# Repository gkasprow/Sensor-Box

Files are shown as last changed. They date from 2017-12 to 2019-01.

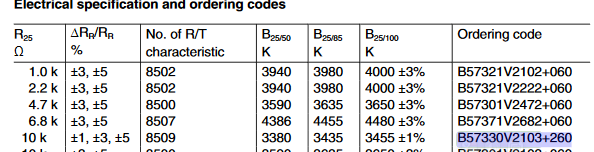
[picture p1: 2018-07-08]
Sensor_Box_Hardware/Sensor-Box/Sensor_Box_PWR_Backup/Thermistor.PNG

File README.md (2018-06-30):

# Sensor-Box
Multichannel standarized enviorement for home automation and other MQTT applications

This is design of modular, DIN-based system for hme automation and industrial control.
There are several great open-source SW enviorements like Cayenne, Blynk, Node Red. They are used to control breadboard stuff built with Arduino, RPI and extension modules.
What I miss the most is well designed hardware that fully explores potential of the software.
So I designed several base and extension modules. The idea is very simple - there is controller module based on Arduino, ESP32 or Linux platform.
From its left side one plugs connectivity modules like Ethernet, LoRa, GPRS and supply like DC, AC, PoE, battery backup.
From its right side one can plug any number of extensions like energy meters, relays, Lighting drivers. One can also connect external sensors using CAN bus.
Several existing technologies were used to build the system, to count a few: HAPCAN, Arduino, Node Red, Cayenne.
More information is available on Wiki page.

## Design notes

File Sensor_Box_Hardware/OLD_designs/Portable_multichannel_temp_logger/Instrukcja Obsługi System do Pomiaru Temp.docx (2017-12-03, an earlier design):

Wielokanałowy system do pomiaru temperatury

User Manual

1. Podstawowa obsługa urządzenia

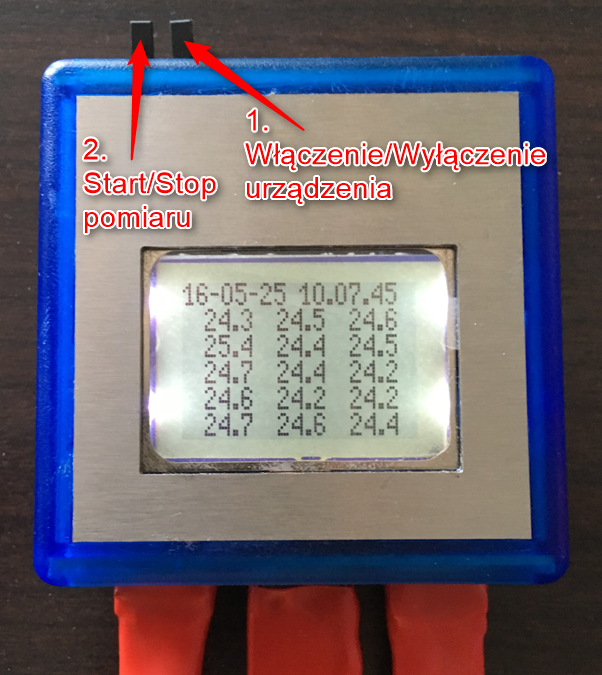
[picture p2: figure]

2. Zapis na kartę SD.

Urządzenie automatycznie zapisuje wszystkie pomiary raz z ich czasem oraz wszystkie wyświetlane komunikaty do pliku LOG.TXT.

3. Konfiguracja urządzenia

Konfiguracja urządzenia możliwa jest zmianę wartości parametrów pliku config.txt. Lista parametrów przedstawiona jest w poniższej tabeli:

Parametr: | Opis: | Przykład definicji:
D | Aktualna wartość data | D20160505 (D20YYMMDD)
T | Aktualny wartość czasu | T201238 (THHMMSS)
M | Tryb Kalibracyjny | M
m | Tryb Pomiarowy | m
N | Włączenie pomiaru poszczególnego czujnika, x- numer czujnika, defaultowo czujnik jest wyłaczony | N10 (Nx)
F | Wyłączenie pomiaru poszczególnego czujnika, x- numer czujnika | F10 (Fx)
c | Wartość wyjścia przetwornika w temperatu- rze T0, x – numer czujnika, yyyyyyy – wyjście przetwornika | c01 3018165 (cxx yyyyyyy)
C | Wartość wyjścia przetwornika w temperatu rze T1, x – numer czujnika, yyyyyyy – wyjście przetwornika | c01 4770612 (Cxx yyyyyyy)
T0 | Mniejsza temperatura do kalibracji czujnika, x – wartość temperatury | T0 0 (T0 x)
T1 | Większa temperatura do kalibracji czujnika, x – wartość temperatury | T1 100 (T1 x)
I | Czas opóźnienia pomiędzy kolejnymi pomiarami czujników, gdzie x – czas wyrażony w milisekundach | I500 (I x)

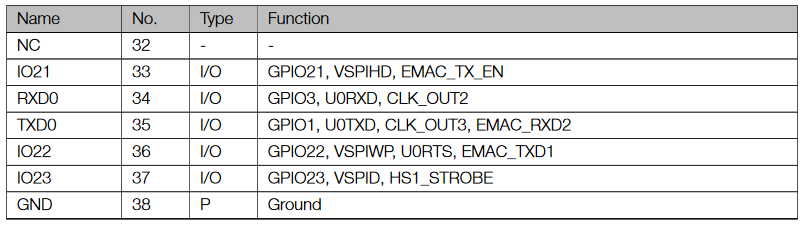
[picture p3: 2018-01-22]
Sensor_Box_Hardware/Sensor-Box/Sensor_Box_Hub/ESP32-2.PNG

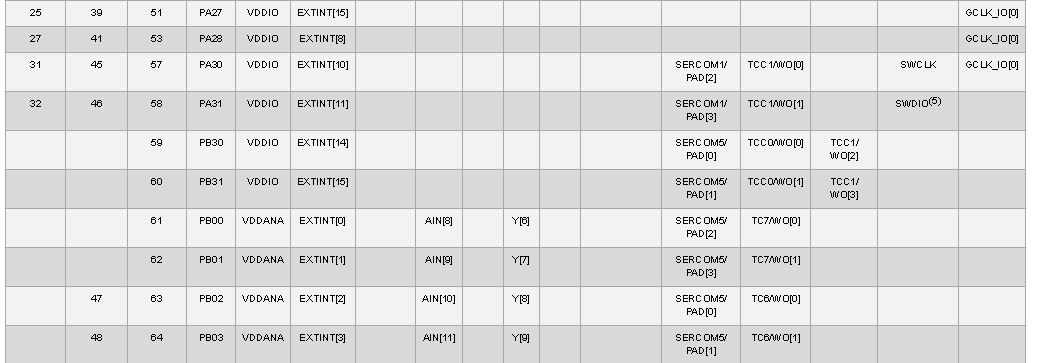
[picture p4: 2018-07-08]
Sensor_Box_Hardware/Sensor-Box/Sensor_Box_Hub_SAMD21/ATSAMD21c.PNG

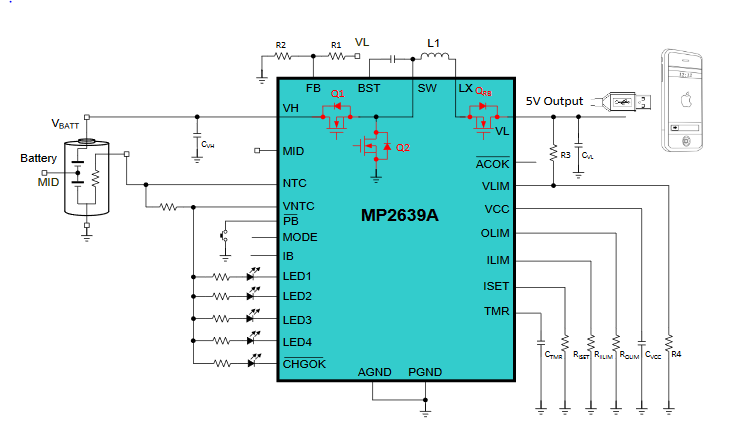
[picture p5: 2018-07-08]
Sensor_Box_Hardware/Sensor-Box/Sensor_Box_PWR_Backup/app_sch.PNG

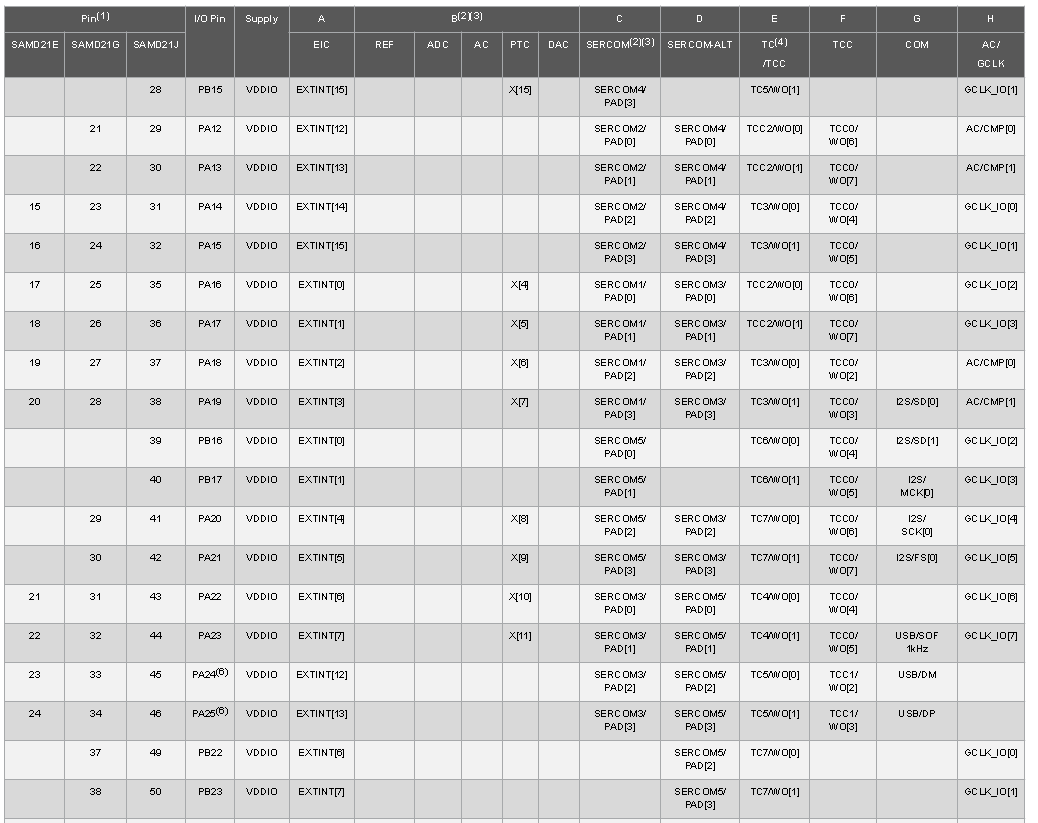
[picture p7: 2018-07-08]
Sensor_Box_Hardware/Sensor-Box/Sensor_Box_Hub_SAMD21/ATSAMD21b.PNG

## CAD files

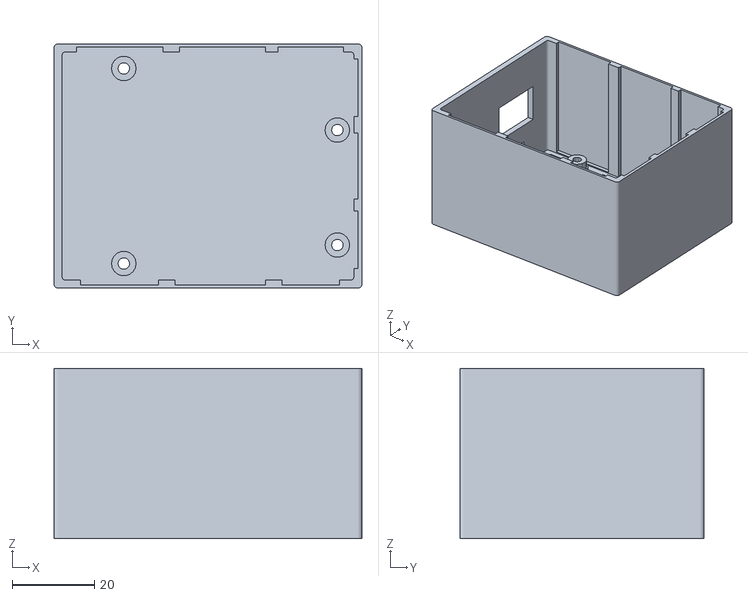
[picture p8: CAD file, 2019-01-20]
LoRa_router/Arduino_box.stl
75.0 x 59.5 x 41.5

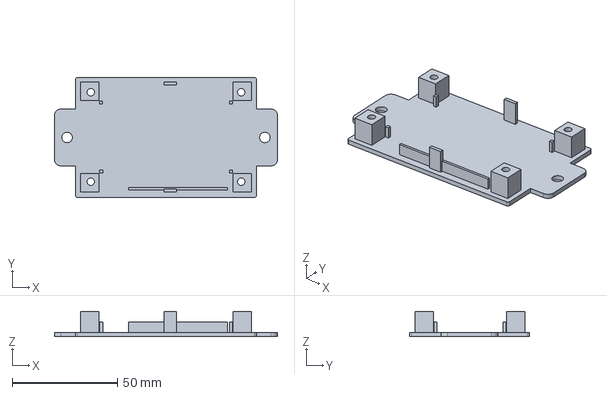
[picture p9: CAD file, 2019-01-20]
Sensor_Box_Hardware/Sensor-Box/Sensor_Box_CAN_SENS/Enclosure/Bottom.stp
106.0 x 57.0 x 12.0 mm

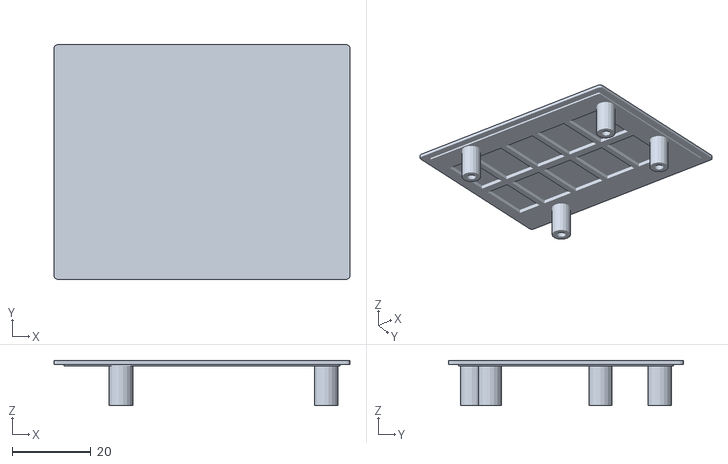
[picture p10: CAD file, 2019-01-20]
LoRa_router/lid.stl
75.0 x 59.5 x 11.5

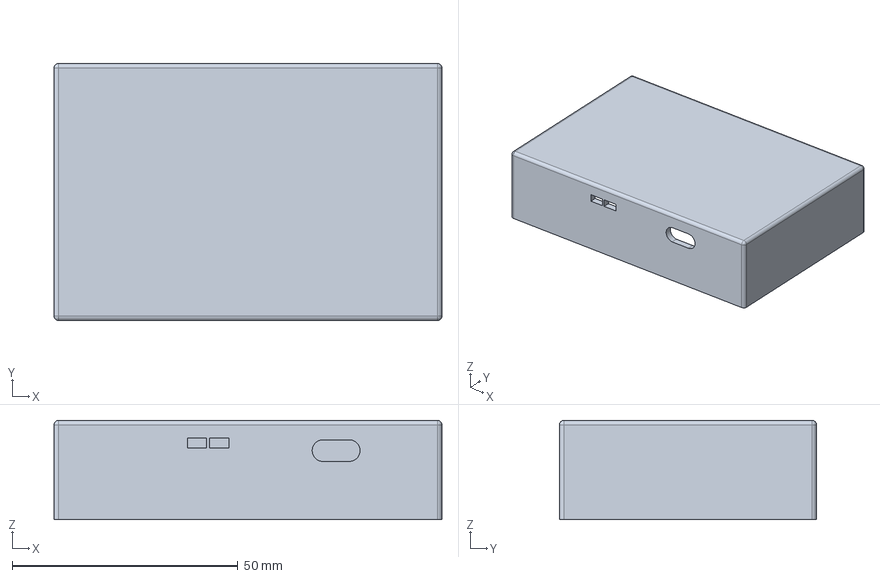
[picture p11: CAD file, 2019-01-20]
Sensor_Box_Hardware/Sensor-Box/Sensor_Box_CAN_SENS/Enclosure/Top.stp
86.0 x 57.0 x 22.0 mm

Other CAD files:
Sensor_Box_Hardware/Sensor-Box/Sensor_Box_CAN_SENS/Enclosure/Bottom.stl
Sensor_Box_Hardware/Sensor-Box/Sensor_Box_CAN_SENS/Enclosure/Top.stl

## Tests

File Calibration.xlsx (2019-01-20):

Voltage ratio | 0.001023751024 | Vout/Vin | Based on your input voltage divider ratios |  |  |  |  |  | L Line Input Impedance | 1000 | Ohm
Current ratio | 0.0145631068 | Vout/Ain | Based on your input current shunt/CT ratios |  |  |  |  |  | V Channel Input Impedance | 975800 | kOhm
 |  |  |  |  |  |  |  |  |  |  |  |  | Impulse converter
MMode |  |  |  |  |  |  |  |  |  |  |  |  | 973 | W
Lgain= | 100: Gain 1 |  |  |  | 100 |  |  |  |  | 1000000000 |  |  | 3.699897225 | seconds per impulse | 0.2702777778 | Hz
Ngain= | 10: Gain 1 |  |  |  | 10 |  |  |  |  |  |  |  | 973 | impulses in one hour | 0.2197802198 | Hz
LNSel= | 1: Meter on L line |  |  |  | 1
DisHPF= | 00: HPF1 and HPF0 |  |  |  | 00
Amod= | 0: Fwd or rev energy pulse output |  |  |  | 0
Rmod= | 0: Fwd or rev reactive energy pulse output |  |  |  | 0
Zxcon= | 10: All zero crossing |  |  |  | 10
Pthresh= | 0010: 3.125% |  |  |  | 0010
Mmode Reg= | 1001010000100010 |  |  |  |  |  |  |  |  |  |  | 0.1125728155
= | 10010100 | 00100010
= | 94 | 22
Mmode Reg= | 0x9422
PL Constant
UN= | 300 | V | Reference voltage, unit is V
Ib= | 30 | A | Basic current, unit is A
GL= | 1 | V/V | L line current circuit gain
VL= | 307.13 | mV | Sampling voltage of the L line circuit at Ib, unit is mV
VU= | 1000.0 | mV | Sampling voltage of the voltage circuit at UN, unit is mV
MC= | 1000 | imp/kWh | Pulse constant of the energy meter, unit is imp/kWh
PL_Constant= | 28626153
= | 01B4CCE9
PLconstH(0x21)= | 0x01B4
PLconstL(0x22)= | 0xCCE9
Small-Power Mode and Power Offset Compensation
1. Disconnect the current circuit of the energy meter;
2. Write '0xA987' to the SmallPMod register (04H) to enter small-power mode
3. Read out L / N line active / reactive power in small-power mode many times to get a mean value;
4. Write the complement of the above mean value to the corresponding L / N line active / reactive power offset registers;
5. Write any non-0xA987 value to the SmallPMod register (04H) to exit small-power mode
L Line Gain Calibration (Calibrate PL Constant Energy Metering)
L line gain calibration is performed when power factor PF=1.0 and the current is Ib
ETSA Frequency | 0.269 | Hz | Pulse output frequency as measured from ETSA metering using photodiode.
My Frequency | 0.219 | Hz | Pulse output frequency as measured from my energymeter using photodiode.
Error % = | -18.58736059 | %
Lratio = | 0.2283105023 |  |  | 65536 |  | 1010 | 10 | 5
Lgain= | 7481 |  | 58054 |  |  | 0101
Lgain= | 0x1D39
Voltage RMS Gain and L Line Current RMS Gain
Vol_mea= | 422.3 | V | Readout value of the Urms register (49H) |  |  |  |  |  |  | 0.007766865298
Un= | 238 | V | Actual Voltage |  |  | hex |  |  |  | 0.2436527437 | 31.37079559
Ugainold= | 54372 |  | 26400 is the default value |  |  | D464
= | 30642
Ugain= | 0x77B2
Cur_meaL= | 1.02 | A | Readout value of the Urms register (49H)
Ib= | 1.02 | A | Actual Voltage
Igainold= | 31251 |  | 31251 is the default value |  |  | 7a13
= | 31251
Igain= | 0x7A13 |  |  | offset=0.003A |  | IgainL | 366
 |  |  |  |  |  |  | 16E
The current offset calibration should be performed at reference voltage and no current.
Calibration is performed by reading the current, multiplying it with the above Igain/2^16 and 2^8,
calculating the complement and writing the result to the L line current offset register (IoffsetL, 35H).
Calibration of voltage offset is similar to that of current offset, but voltage offset
calibration is not applicable for self-powered meter
Voltage Sag Setpoint
Un= | 230 | Nominal voltage
Ugain= | 30642 | From Voltage RMS Gain calc
x%= | 0.94 | 6% below nominal
SagTh = | 8174
SagTh = | 0x1FEE

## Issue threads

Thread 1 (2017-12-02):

CPU selection

gkasprow, 2017-12-02:
I was looking for several CPU options that Cayenne supports and that has all features I need.
And it seems that ESP32 is quite good choice due to its low price and plenty of features.
It lacks IOs, but this can be mitigated easily using low cost extenders.
I built simple test platform to see how already [available Ethernet code](https://github.com/espressif/esp-idf/tree/master/examples/ethernet/ethernet) works.
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
And after some tweaking it really works.  The oscillator needed capacitor circuit to fix an issue reported [here](https://hackaday.com/2017/04/18/enabling-ethernet-on-the-esp32/).

gkasprow, 2017-12-03:
Udate - I made running original ESP8266 code on it. Just a few changes in header file names - rename Wifi.h to ESP32_Wifi.h and comment  lines 43..46 in the file CayenneMQTTWiFiClient.h.
//            if (WiFi.status() == WL_NO_SHIELD) {
//                            CAYENNE_LOG("WiFi shield not present");
//                            while (true);
//            }

gkasprow, 2018-01-06:
Update - Cayenne now supports ESP32 as well, but only Wifi connectivity

gkasprow, 2018-01-06:
In many cases Ethernet connectivity will be needed. ESP32 is fine, but has limited IO resources, i.e. number of UARTS. I checked the  SAM9D21 CPU, popular in Arduino community, priced about 2.5$/pc CPU.
It works with CayenneMQTT library very well.
Cayenne offers several approaches - Arduino and RPi libraries which are configured using top - bottom approach where certain IO or channel is activated from web interface.
There is another library called CayenneMQTT which offer bottom-top approach where data channel is defined by MQTT message type, in the source code. And this is what we need.
So I connected SAM9D21 board from [RobotDyn](https://robotdyn.com/catalog/boards/samd21_m0/)
with Wiznet W5500 board, compiled Cayenne MQTT example design and it works.
So I will prepare 2 main boards - one with ESP8266 + optional Ethernet PHY board and another with SAMD21 with W5500 so developers have choice which way to go.

gkasprow, 2018-06-30:
I want to use Node Red as a main controller. It is very flexible solution and enables ability to integrate literally everything with everything. To make it possible, I designed board with Orange Pi module. But after first experiments I discovered that it takes really a lot of power (more than 5W) and gets very hot after a few minutes.
I found a [tiny board](https://onion.io/omega2/) that is very cheap (~10$), takes 0.6W, has WiFi and Ethernet and enough computing power to do he job.
So I redesigned the hub module to support both Orange Pi zero and Onion Omega 2+

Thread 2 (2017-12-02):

power meter IC selection

gkasprow, 2017-12-02:
I did some survey around power metering ICs.
There are low cost power meter modules from China: [PZEM-004](https://abra-electronics.com/sensors/sensors-current-en/pzem-004t-multifunction-power-monitoring.html) but their accuracy and safety is an issue. I decided to use very low cost chip from [Microchip](http://www.microchip.com/wwwproducts/en/ATM90E26) that has already support for [many platforms](https://github.com/whatnick/ATM90E26_Arduino).
There are also low cost [modules ](https://www.tindie.com/products/whatnick/atm90e26-breakout/) available. Low cost means that it is far less expensive than Microchip devkit.
So I connected things together and started playing with software.
I didn't wanted to use software UART. Anyway, for some strange reason it didn't wanted to work.
So I modified the code to work with hardware serial port on Arduino Leonardo.
Another thing I discovered with this code is that it needs plenty of iterations to calibrate to board. First you have to flash CPU, connect load, ampmpeter, voltmeter, power meter, read values, enter into the code, flash CPU again, then read checksum that the ATM90E26 produces, put it int other code and flash again. Definitely not the way to go.
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

I added Cayenne code and get some measurements via web application. So this approach seem to work well.
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

gkasprow, 2017-12-17:
I did first attempt to build single channel of energy meter in a way that it is scalable and can be extended to any number of channels.
So I assumed that it must be a multi-drop connectivity and the protocol.
There are a few of them : I2C, CAN, RS485, 3-state LVCMOS
For connectivity within same module simple I2C or LVCMOS would do the job.
Protocol could be I2C or MODBUS.
The idea is to daisy-chain several modules.
But we want to have identical modules, with no address switches or jumpers.
The best would be geographical addressing.
And the number of connector pins need to be minimised - preferably 4 or so.
So the idea is to use autoconfiguration during boot time. Something that resembles USB re-numeration.
This could work in following way:
- the master talks to the first device on the bus (address 0). Other devices are disconnected.
- the unit 1 responds (with address 0), master changes its address to 1
- then the unit1 connects (extends) the bus to the unit 2 using analogue switch.
- the mater talks to the second device on the bus (address 0). Units 3,4...n are disconnected
- then the unit 2 responds, master changes its address to 2
- the process continues until anything responds on address 0.
During re-numeration process, the master reads ID table of device that contains descriptor of what the unit does.
In this way after the process is done, we have a set of devices with unique addresses.

This approach works if each device is intelligent, it means that it contains some CPU.
There are very low cost, powerful Cortex M0 MCUs. Their price is below [1$](https://www.digikey.com/product-detail/en/microchip-technology/ATSAMD09D14A-MUT/ATSAMD09D14A-MUTTR-ND/5404071)
The MCU is powerful, i.e. has 4kB of SRAM, 16KB of FLASH and 2 serial interfaces that is sufficient for us.

I can imagine that such measurement channels could be placed side by side to form flat structure. This is critical in case of the fuse-boxes.
Below is the first estimate. Board size is 53.5 x 14mm
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
The board contains connectors for L, N and current transducer, energy metering IC, MCU, crystal, analogue switch and bus connectors.
One can imagine such board extending internal bus to external interface, i.e. MODBUS RTU

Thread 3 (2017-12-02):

Interface selection

gkasprow, 2017-12-02:
To make the stuff modular, we need to choose the interfaces.
We need a way to discover newly connected modules and to communicate with them.
The obvious choice is I2C, but it has one disadvantage - one node can block the bus.
We can of course add bus switches to mitigate such case.
Another thing is its speed. It is not that critical in case of sensor readout, but if you have several such modules, that can become a bottleneck. Good thins is that here are plenty of sensors with I2C interface. But they cannot be placed too far from the controller.

Another popular IFC is SPI.
It's high speed, only one slave is selected at a time.

UART is yet another interface. It's problematic in case of multi-channel controller because needs that much UART peripherals. Sending data is trivial, but reception is not because some sensors (air quality, thermometers, GPS) transmit data asynchronously. There are chips that one can hook up to the [SPI](https://www.nxp.com/docs/en/brochure/75015676.pdf) or[ I2C ](https://www.maximintegrated.com/en/products/interface/controllers-expanders/MAX3107.html)and have as many UART channels as needed. One need a MCU to hook up another type of sensor, however there are ICS that support [UART -I2C/SPI](https://www.nxp.com/docs/en/brochure/75015763.pdf) conversion

MODBUS RTU is much better in this sense because it responds only when requested. It's great and nice to have because one can use COTS components like energy meter, relays, motor controllers, etc. To hook up a sensor one need to use MCU.

Analog signal

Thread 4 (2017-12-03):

air quality sensor

gkasprow, 2017-12-03:
Recently I purchased a few [SDS011](https://www.google.pl/url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) sensors.
First one was connected to Arduino clone - Atmega wih Wiznet chip using a few lines of code.
I equipped it with PoE injection box and placed on my terrace. The house is heated using solid state pellet stove. I can easily observe moments when the stove switches on and switches off - the pollution level exceeds the normal value 10x. My neighbour has identical heating system so things gets worse twice. Luckily, since a few months a gas pipe was laid close to my property so luckily in a few weeks I will switch to much more "eco" heating system.
Example one week plot
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

Then I ported ESP8266 Cayenne wifi to ESP32.
I've noticed during a few weeks of operation that ESP8266 is not very stable. It managed to hang itself.
So I started with ESP32, connected SDS011 sensors and placed them side by side.
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

The measurements are far from what I'd expect
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

gkasprow, 2017-12-10:
Today I noticed quite strange dust level in Warsaw:
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
There are construction works nearby, and it seems that the developer is doing some dusty works right now. Fortunately I have particle filters installed at the air inlets, so inside of the flat don't see any changes.
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

gkasprow, 2017-12-10:
Today I built yet another version of the particle monitor. I used PMS7003 which analyses also PM1. There is ready to use Arduino library, only a few lines of code were needed to integrate it with Cayenne.
I want to use it to test various filter materials in the recuperation system inlet filter.
This is the code that averages 10 readout and publishes measurements every 10 seconds

```
void loop()
{
  if (pms.read(data))
  {
    Cayenne.loop();
if (AV_CNT++<10)
  {
  PM1_AV_Value += data.PM_AE_UG_1_0;
  PM2_5_AV_Value += data.PM_AE_UG_2_5;
  PM10_AV_Value += data.PM_AE_UG_10_0;
  }
else
  {
    AV_CNT=0;
      Cayenne.virtualWrite(0, lastMillis);
      Cayenne.virtualWrite(2,(float)(PM1_AV_Value/10));
      Cayenne.virtualWrite(3,(float)(PM2_5_AV_Value/10));
      Cayenne.virtualWrite(4,(float)(PM10_AV_Value/10));
      PM1_AV_Value = 0;
      PM2_5_AV_Value = 0;
      PM10_AV_Value = 0;
  }
  }

```

gkasprow, 2018-06-30:
I designed more or less final version of the sensor. It is accessible over CAN and supports PMS7003, HDC1000YPA and SGP30 sensors thus enabling complex air quality measurements.
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

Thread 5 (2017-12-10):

Modbus devices

gkasprow, 2017-12-10:
There are many popular industry-grade MODBUS devices that can be used for IoT purposes.
I purchased some of them: energy meters, humidity/temperature sensors, relay boards, UART-RS485 boards, DIN relays, etc.
So that's a pity that it is not supported by Cayenne environment.
So I did some quick setup to test how it works in practice.
I took ESP8266 devkit, ORNO energy meter, relay and built power switch with energy monitor. There are many such devices on Aliexpess, some of them are based on ESP8266. I tested one from Edimax and it works  but sometimes. While in local network it works just fine, outside of it works sometimes. So it is not the way to go. One idea is to replace the firmware with some alternative, another is to connect 15$ energy meter to 2$ ESP devkit and write a few lines of code. Modbus is already supported by Arduino so why not to try.
Here is the bricolage
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

the code is very simple:
``
    result = node.readHoldingRegisters(0, 9);
 if (result == node.ku8MBSuccess)
   {
    Cayenne.virtualWrite(4, (float)node.getResponseBuffer(0x00)/10,"voltage", "Volts"); //voltage
    Cayenne.virtualWrite(5, (float)node.getResponseBuffer(0x01)/10, "current", "Ampere");//current
    Cayenne.virtualWrite(6, (float)node.getResponseBuffer(0x02)/10, "freq", "Hertz" );//frequency
    Cayenne.virtualWrite(7, node.getResponseBuffer(0x03), "pow", "Watts");//Active power
    Cayenne.virtualWrite(8, node.getResponseBuffer(0x04), "pow", "Watts");//Reactive power
    Cayenne.virtualWrite(9, node.getResponseBuffer(0x05), "pow", "Watts");//Apparent power
    Cayenne.virtualWrite(10, (float)node.getResponseBuffer(0x06)/1000);//Power factor
    Cayenne.virtualWrite(11, (float)(node.getResponseBuffer(0x07) *256 + node.getResponseBuffer(0x08))/1000);// Active energy
    Cayenne.virtualWrite(12, node.getResponseBuffer(0x03), "pow", "Watts");//Active power
     }
	}
``

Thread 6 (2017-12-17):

Modularity and scalability

gkasprow, 2017-12-17:
As it was already [posted](https://github.com/gkasprow/Sensor-Box/issues/2#issuecomment-352221718), I plan to utilise modular construction which can be extended to visually any number of channels.
On the other hand, I want to have in addition:
- Ethernet
- PoE
- GSM module
- LiPo supply option
Enclosure is another issue that need to be discussed separately.
So far I sketched schematics for:
- power meter
- PoE
- Ethernet module
- Hub

The modules can be arranged in the following way:
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

On the left side we have PoE, then Ethernet, hub and 3 power meters.
At the moment the connectors are 4 pin, but I consider adding also I2C wires and one custom wire for remote firmware upgrade. Maybe +12V would be feasible for high power applications.

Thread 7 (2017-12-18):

Enclosure

gkasprow, 2017-12-18:
I'm looking for nice enclosure that fits both DIN rail and can work stand-alone.
It needs to be modular and low cost.
And it seems I found ideal candidate. They are produced by several manufacturers, i.e. [Camdenboss](http://camdenboss.com/interface-modules/mini-series-72mm-empty-modular-interface-supports) and OKW. Example from OKW:
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
They are available with DIN mounting and without it. The segments are below or just above 1 EUR.
Available widths: 11.25, 22.5, 45mm and multiples

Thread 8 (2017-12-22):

Connectors

gkasprow, 2017-12-22:
After long search I found connectors that fit the purpose very well.
They are low cost , below 1$ per piece, and are idiot-proof. Maximum pin count is 10 which is sufficient for our purpose.
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

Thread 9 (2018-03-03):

CAN support

gkasprow, 2018-03-03:
I build a house and started looking for a home automation system that has several features:
 - it is not wireless. I have so much issues with wireless system that I simply do not trust it. They are easy to jam, run on battery.
- I told electricians to install twisted pair cable along all switches and places where potentially will be equipment installed which I want to control. This includes gas furnace, recuperation, alarm, fire sensors, shutters etc.
- the home automation system need to be failure proof, I mean that once electronics is dead, all critical switches must work.
I started looking for a system that supports such operation mode over twisted pair and the only I found is KNX.
The drawback is that in every device one must use quite expensive transceiver. There are a few vendors, but the cheapest transceivers are 6$ at 100pcs. I'd like to keep the entire price of the switch node at such level.
Another standard that is gaining popularity in home automation is CAN, known from automotive industry.
And I found quite interesting, [decentralised home automation](http://hapcan.com/) system based on CAN.

gkasprow, 2018-06-30:
To add support to Linux module, I initially implemented MCP2515 CAN controller.
But it is not well supported in Linux due to lack of buffering. One can write [bit-bang Linux driver](https://github.com/GBert/openwrt-misc/tree/master/mcp2515-banged) that is not very elegant solution
Another solution is to use existing implementation of UART/USB to CAN based on small MCU.
I found a few, the most interesting is [one](https://github.com/UsbCANConverter-UCCbasic) based on low cost STM32 Cortex M0 CPU (~2$ chip).
I ordered 2 pcs on [Tindie](https://www.tindie.com/products/lll7/can-usb-converter-uccb/) and will test them once they arrive.
I also replaced MCP2515 with STM32 solution to get rid of future problems with decoding of CAN frames.

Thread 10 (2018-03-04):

Availability

jordens, 2018-03-04:
Where and when and what price?

gkasprow, 2018-03-04:
@jordens,  this was not meant as a commercial project.
I design it in my free time as a hobby project to keep some balance between work and life :)
These are simple things that simply work and give satisfaction.
However if you or someone else want to contribute, I can make a few more copies of the hardware.
I will produce it as a single multi-board project to keep the tooling cost low.
So far I managed to test critical functionalities and confirmed chipset selection using devkits. Essential parts of these boards (PoE, GPRS, Ethernet, CAN) were already verified in other projects.
When? That's good question. I started it 3 months ago and spend roughly one day per week on it. Within a month I plan to produce it. Then SW development will take yet another 2 months. Most of it will be based on verified Arduino or Cayenne libraries so it should be quick. In the summer I want to install it in my 2 houses and in my flat in Warsaw.

gkasprow, 2019-05-29:
The HW has just arrived.
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

jordens, 2019-05-29:
Nice! Did you have a chance to change the dimensions slightly as for the banker io modules?

gkasprow, 2019-05-29:
You discovered that issue after I sent it for production.

quynh-nn, 2019-05-30:
Great! How do these modules connect to each others? And how do these modules connect hardly with each others (I mean a vibrated protection)?

gkasprow, 2019-05-30:
they are connected by [edge connectors](https://pl.mouser.com/datasheet/2/40/OpenEndedCard%20Edge_00-9159-1125649.pdf)
The modules are enclosed in [DIN shells](https://www.tme.eu/Document/90ae178fa75e7b415a1db063121a9557/DIN-72-11.pdf)

quynh-nn, 2019-05-31:
Perfect!

gkasprow, 2019-06-04:
@jordens I tried these modules with DIN enclosures from[ ELBAG ](https://www.tme.eu/Document/90ae178fa75e7b415a1db063121a9557/DIN-72-11.pdf)and they fit perfectly.
I also tried with enclosures from Italtronics and they need some force during insertion and indeed, could be 0.5mm shorter. Which enclosures did you use? Camden?

jordens, 2019-06-05:
Camden. Their drawings have the width of the slot at 72.4 mm.

jordens, 2019-06-05:
Maybe the polish/Italian have more accurate injection molds than the British...

jordens, 2019-06-07:
And the Banker IO boards that I got are actually 72.8 mm plus the break-off tab residue (~0.2 mm on each edge). The Camden slots are 72.4 mm in reality. So that's an issue with the boards.

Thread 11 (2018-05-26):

interface between the modules

gkasprow, 2018-05-26:
The more I think about the interface between modules, the less I'm convinced that LVCMOS signalling would do the job. Sooner or later somebody will try to hot-plug the modules and in this way will damage them because the connectors I use do not have any form of power sequencing.
RS485 transceivers are not expensive - cost of SNx5176B is 0.3$ at high quantity.
So the idea is to modify the device discovery procedure:
- all modules are connected in parallel by RS485.
- each module has single input and output. Input is routed to reset signal, output is controlled via MODBUS register.
By default, module is in reset state and the output is Hi-Z
 The procedure is simple:
1. The host releases reset.
2. The host talks to the first and the only device on the MODBUS. Its address is 0xFF. The host changes it to 0x01 and sets active output that releases reset of next device.
3. the host talks again to the address 0xFF and changes its address to 0x02. It again sets active output that releases reset of next device.
4. It repeates previous step increasing the assigned address until there is something that responds to 0xFF address.
The method proposed has yet another advantage - the host can always reset whole chain. The reset will propagate through all devices.

jordens, 2018-06-01:
The only disadvantage is that a single broken or crashing node will reset everything downstream. If you have pins, you could have that reset line open collector and the reset segment between two nodes be bidirectional. Then you could access the chain from both ends and be resistant to some types of failures.

gkasprow, 2018-06-03:
@jordens I have 4 free pins. All modules simply propagate them from left to right for future applications. So I can simply use them to feed any signal to the end of the chain and back by adding the end-cap module.
I can't imagine how open collector reset line can be controlled both by the host CPU and the device.
Do you mean adding another reset line which propagates the signal in opposite direction ?

jordens, 2018-06-04:
In your description is seemed that the only signal that breaks the left-right symmetry is the reset (it only goes from left (input) to right (output) and is intercepted at each node). I was wondering whether that was necessary.
Let's say you have the reset (active high) segment between two modules weakly pulled high by both. Then use the logical AND of both sides to reset the module and if it receives (let's say) an odd address, it will pull down the right reset line, with an even address it will pull down the left reset line. In both cases you get access to the next module and can start configuring it.

gkasprow, 2018-06-04:
That's good idea - you can start configuring devices from either side.
The controller can configure devices from one side so far it gets any response, and then try from other side to make sure all modules except for broken one are configured. The only problem is in the case when the first device keeps the  left reset line low and the last module keeps the right reset line low so the controller cannot reset all the chain. This can be solved by introducing different pull levels.
The device can pull let's say with 1mA but the controller can overwrite it and force the high state.

jordens, 2018-06-04:
Yes it's only a way to debug at most a single failure.

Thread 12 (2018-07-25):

water flow controller

gkasprow, 2018-07-25:
Due to high temperatures in Poland I started rebuilding my air-conditioning system. It's design is quite non-standard since I use water to chill the air.
The recuperation installation was equipped with water-air heat exchanger.  I have own water source which I use for watering my garden.  But there are other users that also use the water (i.e. my neighbour) so the water flow is not deterministic. For AC operation, there must be continuous water flow to keep nice 20 degrees air temperature.
So I decided to build water flow controller that keeps minimum flow over the heat exchanger. Water is dumped to the micro-drip watering line. I don't want to keep it operating all the time because that would be  too much for my garden. I.e. during night the air temperature drops below 19 degrees so there is no need to chill it. During the day temperature exceeds sometimes 38 degrees.
The idea is simple - install water flow meter with pulse output, motor-controlled valve, two temperature sensors and make a controller that takes care of it.
Moreover, I want to optimise the water flow to  keep the well pump operation minimal to save energy.
So I purchased set of equipment, built simple controller and I'm going to have fun.

gkasprow, 2018-08-08:
And here is full installation
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

gkasprow, 2018-09-18:
Firmware is [here](https://github.com/gkasprow/Sensor-Box/tree/master/MQTT_firmware/ESP8266_water_flow/ESP8266_water_flow)

gkasprow, 2018-09-18:
And the control panel..
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

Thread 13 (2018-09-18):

soil moisture sensor

gkasprow, 2018-09-18:
One day the water distribution failed  - one of the tubes slipped off the filter terminal and plants were not watered for a few days. Another time, I shut down the main water valve and left home for one week. Plants hardly survived. This was my inspiration to build distributed humidity sensor.
I want to have following features:
- long range. At one place the garden is 1ha big, I want to have ability to monitor some plants far away from nearest building. So it cannot work over Bluetooth. I preserve some plants during the winter time in the cellar, there is no WiFi available, so standards like LoRa seem to be fine.
- I want to measure humidity, and not just condition that it is humid or dry. So certain accuracy is desired. I want to correlate individual plants condition with humidity in long time. I found an article which says that measurement frequency need to be more than 50MHz. With such frequency there is linear relationship between probe capacitance and humidity in the soil and the measurement does not depend strongly on solil type
- I want it to run on CR2032 or AAA battery more than one year. One measurement per hour is sufficient.

So i built simple circuit to check proof of principle.
The schematic is simple:
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
The generator built on the Schmidt inverter generates ~50MHz square wave which is fed to the divider that consists of the capacitance probe and R9. Resulting voltage is rectified and fed to the uPC ADC input.
The sensor is piece of FR4 with two long strips, covered by plastic sleeve.
This is very simple but has some bottlenecks:
- the frequency varies a lot between gates so another board may oscillate at 60MHz and yet another at 40MHz.
- the temperature coefficient of diode can be essential because the output voltage difference is low, less than 400mV between dry sensor and immersed in water.
So next iteration needs to have compensation circuit which is formed by another dummy divider and detector. I needs to be driven from another negator to not influence the main one.
The range of ADC is 2.5V, so let's amplify the detector output a little.
The amplifier does not like the input voltages very close to zero, and diodes need to be polarised continuously so let's shift the voltage to half of VCC. So removal of C6 would do the job.
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

gkasprow, 2018-09-18:
Frequency stability can be improved by adding crystal generator. But popular low cost oscillators are 25, 48, 50 or 100MHz. And still they cost at least 1$ per piece. But we need plenty of that sensors.
We already have hex inverter IC, so let's try to build oscillator out of gates.
Here is example circuit
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 borrowed from [here](https://assemblergames.com/threads/mod-mega-drive-2-pal-60hz-color-fix-with-a-2-pin-crystal.49686/).
But still, there are not such crystals that run at 80MHz. We need to run ordinary crystal at third overtone.
This is example configuration that would do the job
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. I borrowed it from [here](http://www.beckwithelectronics.com/abracon/quartzan.htm)
In an overtone mode, an additional inductor LI and capacitance CC is required to select the 3rd-Overtone mode, while suppressing or rejecting the fundamental mode.
The Lc tank may be located at either input or output of the inverter. However, the Lc tank at the out put is referred, because it helps to clean up all unwanted modes before signal goes through the crystal.
We cannot use Schmidt type negator, we need to have linearised inverter which acts as linear amplifier.
Finally we end up with something like this:
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
C13 and L2 are tuned at 81MHz, C5 and C12 give together 19pF which is close to 18pF required by the crystal.

jordens, 2018-09-18:
Or go the classic 555 route. There are a bunch of boards like that on aliexpress for a $.

gkasprow, 2018-09-18:
Yes, but they use very low frequency. And they have accuracy similar to the human finger :) . Some use resistive method which degrade over the time. I have very different soil types around my home so want to measure it "properly". I know that this can be done easier, but FDR probe gives quite good results. I even purchased 2 of [them](https://www.tindie.com/products/pinotech/soilwatch-10-soil-moisture-sensor/) and I'm currently testing it. I like its shape and accuracy and want to build something similar. It inspired me. The circuit is molded in plastic but I assume it works in similar manner as the circuit above. I will calibrate it with various soil types and later on maybe write some paper on my research :)

gkasprow, 2018-09-18:
And here is preliminary drawing of the device implementing the features above:
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

To lower the cost, helical antenna is also integrated with the PCB

gkasprow, 2018-09-18:
And here is the proof of the very first concept with single detector circuit;
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

muz0k, 2020-04-18:
Hi Sir,
After two years later, I decide to make one for myself but can not decide if copying the same circuit you build or adding/changing some components with my very limited knowledge of electronics. I want to ask some questions. I just this circuit be more sensitive. If I could ever complete it, it will measure the moisture of hazelnut by sticking two needles(for me they are probes) inside a hazelnut.(I can't find any hazelnut moisture meter, there are meters for almost all other grains.)
First: Why didn't you add a resistor (Rs) before crystal? I don't know it is a must but it is said to be lifesaver of crystal.
Second: Instead of 27mhz crystal, can I use bigger ones like 30 or 40/50? Does it make circuit better or not?
Third: Can I use 74hc04 instead of lvc04? If yes, do I need rearrangement of components?(I hope not)
Last one: How about adding MCP3421(18bit adc with I2C)? To make measurement more sensitive(most probably the microcontroller I will use esp32, so much so good)
I am really looking forward to hear you as soon as possible.
Thanks in advance.
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

gkasprow, 2020-04-18:
> First: Why didn't you add a resistor (Rs) before crystal? I don't know it is a must but it is said to be lifesaver of crystal.

The logic gate already has a resistance which is sufficient in this case

> Second: Instead of 27mhz crystal, can I use bigger ones like 30 or 40/50? Does it make circuit better or not?

Actually, there are no 50Mhz crystals. These are ones for smaller frequency that run on usually third overtone. That’s why you need LC circuit. This circuit does not work on 27MHz but on 3*27Mhz

>Third: Can I use 74hc04 instead of lvc04? If yes, do I need rearrangement of components?(I hope not)

what's wrong with HC04?
I didn't try, but this should work

>Last one: How about adding MCP3421(18bit adc with I2C)? To make measurement more sensitive(most probably the microcontroller I will use esp32, so much so good)

This circuit won't benefit anything from 18bit ADC. Temperature stability and the method won't give you accuracy better than a few %. However if you need to detect subtle changes in humidity increasing ADC resolution may help, but don't expect anything better than noise.

muz0k, 2020-04-19:
Dear sir,
I really thank you for your time and fast answers. I am on adc noice suppression research.

ikotzig, 2020-08-09:
Dear Greg,

My name is Ivan Kotzig, I am from Slovakia. I also want to make inexpensive, but above average sensor. I can invest into tooling, as I own a molding company.

Did you advanced further from the above schematics? I was considering a 100MHz circuit I found on Internet, but the components cost about 10 Eur, which is above my intentions.

I am a firmware developer, so I plan to ad an inexpensive CPU to your above schematics. I need 16 sensors connected by wire, not a long distance.

Any information would be welcome.
Ivan Kotzig
ivan<at>toolsquare<dot>com

[100MHz_sensor.pdf](https://github.com/gkasprow/Sensor-Box/files/5047943/100MHz_sensor.pdf)

gkasprow, 2020-08-15:
The entire design (sch and PCB) is already in the repo. I built the PCB, I also done some FW development but have other priorities right now.

petergzmo, 2021-02-21:
> The entire design (sch and PCB) is already in the repo. I built the PCB, I also done some FW development but have other priorities right now.

@gkasprow can you tell me where the sch and PCB are located in this repo?  I can't seem to find them...

gkasprow, 2021-02-23:
it's here
https://github.com/gkasprow/Sensor-Box/tree/master/Sensor_Box_Hardware/Sensor-Box/Sensor_Box_LoRa_Flower_Wachdog

ollyboy, 2022-01-11:
Your design is very good. Did you do any testing, would be great to see some real world results

gkasprow, 2022-01-11:
A batch was produced. I will install them once the spring comes :)

ollyboy, 2022-01-12:
if you use mcpl604 and the spare gates you could have 3 sensor circuits, top, middle, lower. This would provide better data and eliminate the possibility of misleading low capacitance paths in soil with organic materials and debris. Also maybe some gain on the output to get 0-3.3v range. Also why the 10k on output, would not <1k be better given micro controller ADC impedance.

ollyboy, 2022-01-12:
LT6905 oscillator may be better than xtal for single probe design, cheaper than the xtal,chip,inductor combo

gkasprow, 2022-01-12:
@ollyboy This design is good enough. One can make it much more precise, of course. But the question is what you want to achieve. I want to know if my plant is dying or not ;) It's not laboratory equipment. The 10k output resistance does not matter. The ADC S&H circuit needs low impedance and it's provided by a 1nF cap. The S&H circuit draws ns-scale current pulses from the source, if you leave just 1k resistor, it would be far too high. 1nF cap does the job nicely. LTC6905 is fine, but these days chips appear and disappear. It's easier to find replacement for classic crystal or logic gates.

delta77101, 2022-12-06:
Is there any further update on this design? Did you run any tests on your original set of boards? What range of voltages did you end up getting from dry to fully wet soil?

gkasprow, 2022-12-06:
Didn't do any other tests. I installed an automatic off-the-shelf irrigation system, so don't care about individual plants' moisture.

anilaras, 2024-11-19:
hello, I tried to make my own soil moisture sensor by modifying your circuit a little and using probes. However, when I examine the sens_out pin of the sensor with an oscilloscope, I see that there is a strange frequency wave here, not an analog voltage value. Is there a mistake in my design or is it supposed to be like this? How do I measure this value with an adc and make sense of it?
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![Uploading WhatsApp Görsel 2024-11-19 saat 14.08.08_e7c03240.jpg…]()

gkasprow, 2024-11-19:
what modifications did you make?
Where do you measure your signal? How do you connect the ground?
you get 20mV of noise, which may be acceptable, what is DC component?

gkasprow, 2024-11-19:
You need to adjust the generator resistor values to match your probes impedance otherwise you will saturate the amplifier

gkasprow, 2024-11-19:
the same applies to the capacitance

anilaras, 2024-11-19:
I know I'm asking too many questions, please excuse me. But I don't have much training in analog electronics. I wonder how I can measure the impedance of the probes and adjust the resistance and capacitor values   accordingly. Is it possible for you to point me to a source or a way where I can read and learn about this subject?

gkasprow, 2024-11-19:
just increase the resistor values, I'd start with 2x. Capacitance can be measured using DMM

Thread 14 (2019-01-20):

PT100/PT1000 support

gkasprow, 2019-01-20:
Recently I needed to measure the distribution of temperatures inside of the electronic enclosure.
The one-wire sensors are bulky and they would simply affect the measurements of i.e. individual ICs.
There are hover tiny 0603 or 0805 ceramic platinum sensors. They are easy to glue, have very thin wires that can be extended using thin magnet wire.
I needed readout IC. There is a very popular one from Maxim [MAX31865](https://datasheets.maximintegrated.com/en/ds/MAX31865.pdf) that seems to fit my needs perfectly. There is already Arduino support, so I decided to design a dedicated extension module for my system.
The module would support the connection of up to 4 such sensors in 2 or 4- wire configuration. it is based on the energy meter module, but with other analog front end chip.

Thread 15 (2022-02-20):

UPS errata

gkasprow, 2022-02-20:
LED anodes must be connected to VCC, not VNTC
R205 = DNP, PB has own very weak pullup
R204 =DNP, add divider and pullup to VH or external supply (VCC?)
C212 = DNP
T18 needs checking,
thermistor signal shorted to GND by polygon
balancing does not work (it works sometimes), short MID to GND
CPU won't work here because in hibernation mode it won't have a supply

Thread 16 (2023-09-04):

ESP32 controller errata

gkasprow, 2023-09-04:
- [ ] wrong package for BD5230FVE-TR
- [ ] BD5230FVE-TR supply must be connected to EN line
- [x] NE555 triger line must be tied to MODUS_DI
- [x] NE555 capacitance should be 100nF to woro with 9600 baud
- [x] missing bias of RS485 bus (2x680R)
- [x] mdc_pin: GPIO14 mdio_pin: GPIO15, MDIO cannot share line with U0_TXD
- [x] AUR9713AGH EOL
- [x] LQH44PN2R2 hard to source
- [x] add addressed SPI connector; remove CAN

gkasprow, 2025-02-13:
https://github.com/elhep/GEM_HVSUP_eFUSE/issues/1#issuecomment-1895410054

gkasprow, 2025-02-15:
- [ ] consider adding buffered SPI; IO25, IO 12 and IO2 are strapping pins

gkasprow, 2025-02-21:
- [ ] add reset output pullup

gkasprow, 2025-02-22:
it's not well documented feature but the module ESP32-WROOM-32E (4MB) uses
ESP32-D0WD-V3  or ESP32-D0WDR2-V3; since we don't have PSRAM, ESP32-D0WD-V3  is installed.
For some reason, the voltage level at IO16 and IO17 is 3.3V, which means that the internal FLASH is supplied from 3.3V as well

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

the VDD_SDIO depends on strapping pins

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

default values are here
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

So, for this configuration, we don't need the level translator or IC1 VCCA should be supplied from 3.3V.
I'd leave the assembly option because new ESP32 revisions may have VDDIO fixed at1.8V

gkasprow, 2025-02-22:
- [ ] add pulldown for RESET transistor - 22k between base and GND does the job

gkasprow, 2025-05-25:
- [ ] DEV_RESETn generated by I2C port expander comes too late. SPI peripherals get initialised when reset is active and are not detected.

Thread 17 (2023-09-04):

Ethernet module errata

gkasprow, 2023-09-04:
- swap CRS_DV with RX_DV
- wrong package for BD5230FVE-TR; we don't need it anyway
- add TVS and series resistors for Ethernet lines

Closed 2024-07-29.

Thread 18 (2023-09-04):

BMS errata

gkasprow, 2023-09-04:
- replace 4051 with MAX4051AEEE+ due to leakage
- input resistors = 7.5M (5M+2.5M)
- missing -2.5V supply for instrumentation amplifiers. They need -2.5V supply to support input voltages close to 0.

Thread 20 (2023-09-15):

relay module errata

gkasprow, 2023-09-15:
- [ ] add ID switch

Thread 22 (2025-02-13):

ADC module errata

gkasprow, 2025-02-13:
- [ ] R3 must be pulled down

gkasprow, 2025-02-13:
- [ ] make 10k pullups higher, 100k or so

gkasprow, 2025-02-15:
- [ ] add 100k pulldowns at opamp inputs. Otherwise, they overdrive the ADC

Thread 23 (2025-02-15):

PWM module errata

gkasprow, 2025-02-15:
- [ ] CSn must be pulled down

gkasprow, 2025-02-15:
- [ ] when RESET is inactive, the PCa chip blocks the bus forcing MISO low; when RESET is active, MISO=High Z
add 3 state buffer like 1G125

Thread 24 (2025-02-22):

SENSOR Box Power Meter VT errata

gkasprow, 2025-02-22:
- [ ] R swapped with T
- [ ] dying DC/DC converter when voltage exceeds 10V

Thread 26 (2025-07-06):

new modules dedicated to quantum labs

gkasprow, 2025-07-06:
1. New revision of the main board. We eliminate RMII and utilise the newer ESP32-S3 chip, which offers more I/O. We need more IOs to address multi-chip peripherals. We also eliminate the I2C expander and the level translator.
2. Ethernet + PoE via SPI based on DM9051 MAC+PHY. It has ESP-IDF drivers. Design based on Single Pair Ethernet module (SPE-SPI)
3. RF detector based on a single-chip logarithmic converter and ADC with SPI. Use a precise detector like AD8318 + simple to use 16bit ADC like ADS1118 / MCP3561
4. DAC output 0-10V
5. 2-channel UART based on [WK2168 or WK2132-ISSG](https://esphome.io/components/weikai.html); dedicated to sensors transmitting data over UART. Route Rx, Tx, GND, 5V to the connector
6. Precise thermometer based on ad7172; just copy AFE from [Thermostat ](https://github.com/sinara-hw/Thermostat)design

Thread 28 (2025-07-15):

Magnetometer AFE

gkasprow, 2025-07-15:
OSC1= > ECS-3225MV-500-BN-TR3

gkasprow, 2025-08-06:
missing CRESET pullup

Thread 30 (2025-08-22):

relay driver

gkasprow, 2025-08-22:
wrong ULN2803CDWR footprint

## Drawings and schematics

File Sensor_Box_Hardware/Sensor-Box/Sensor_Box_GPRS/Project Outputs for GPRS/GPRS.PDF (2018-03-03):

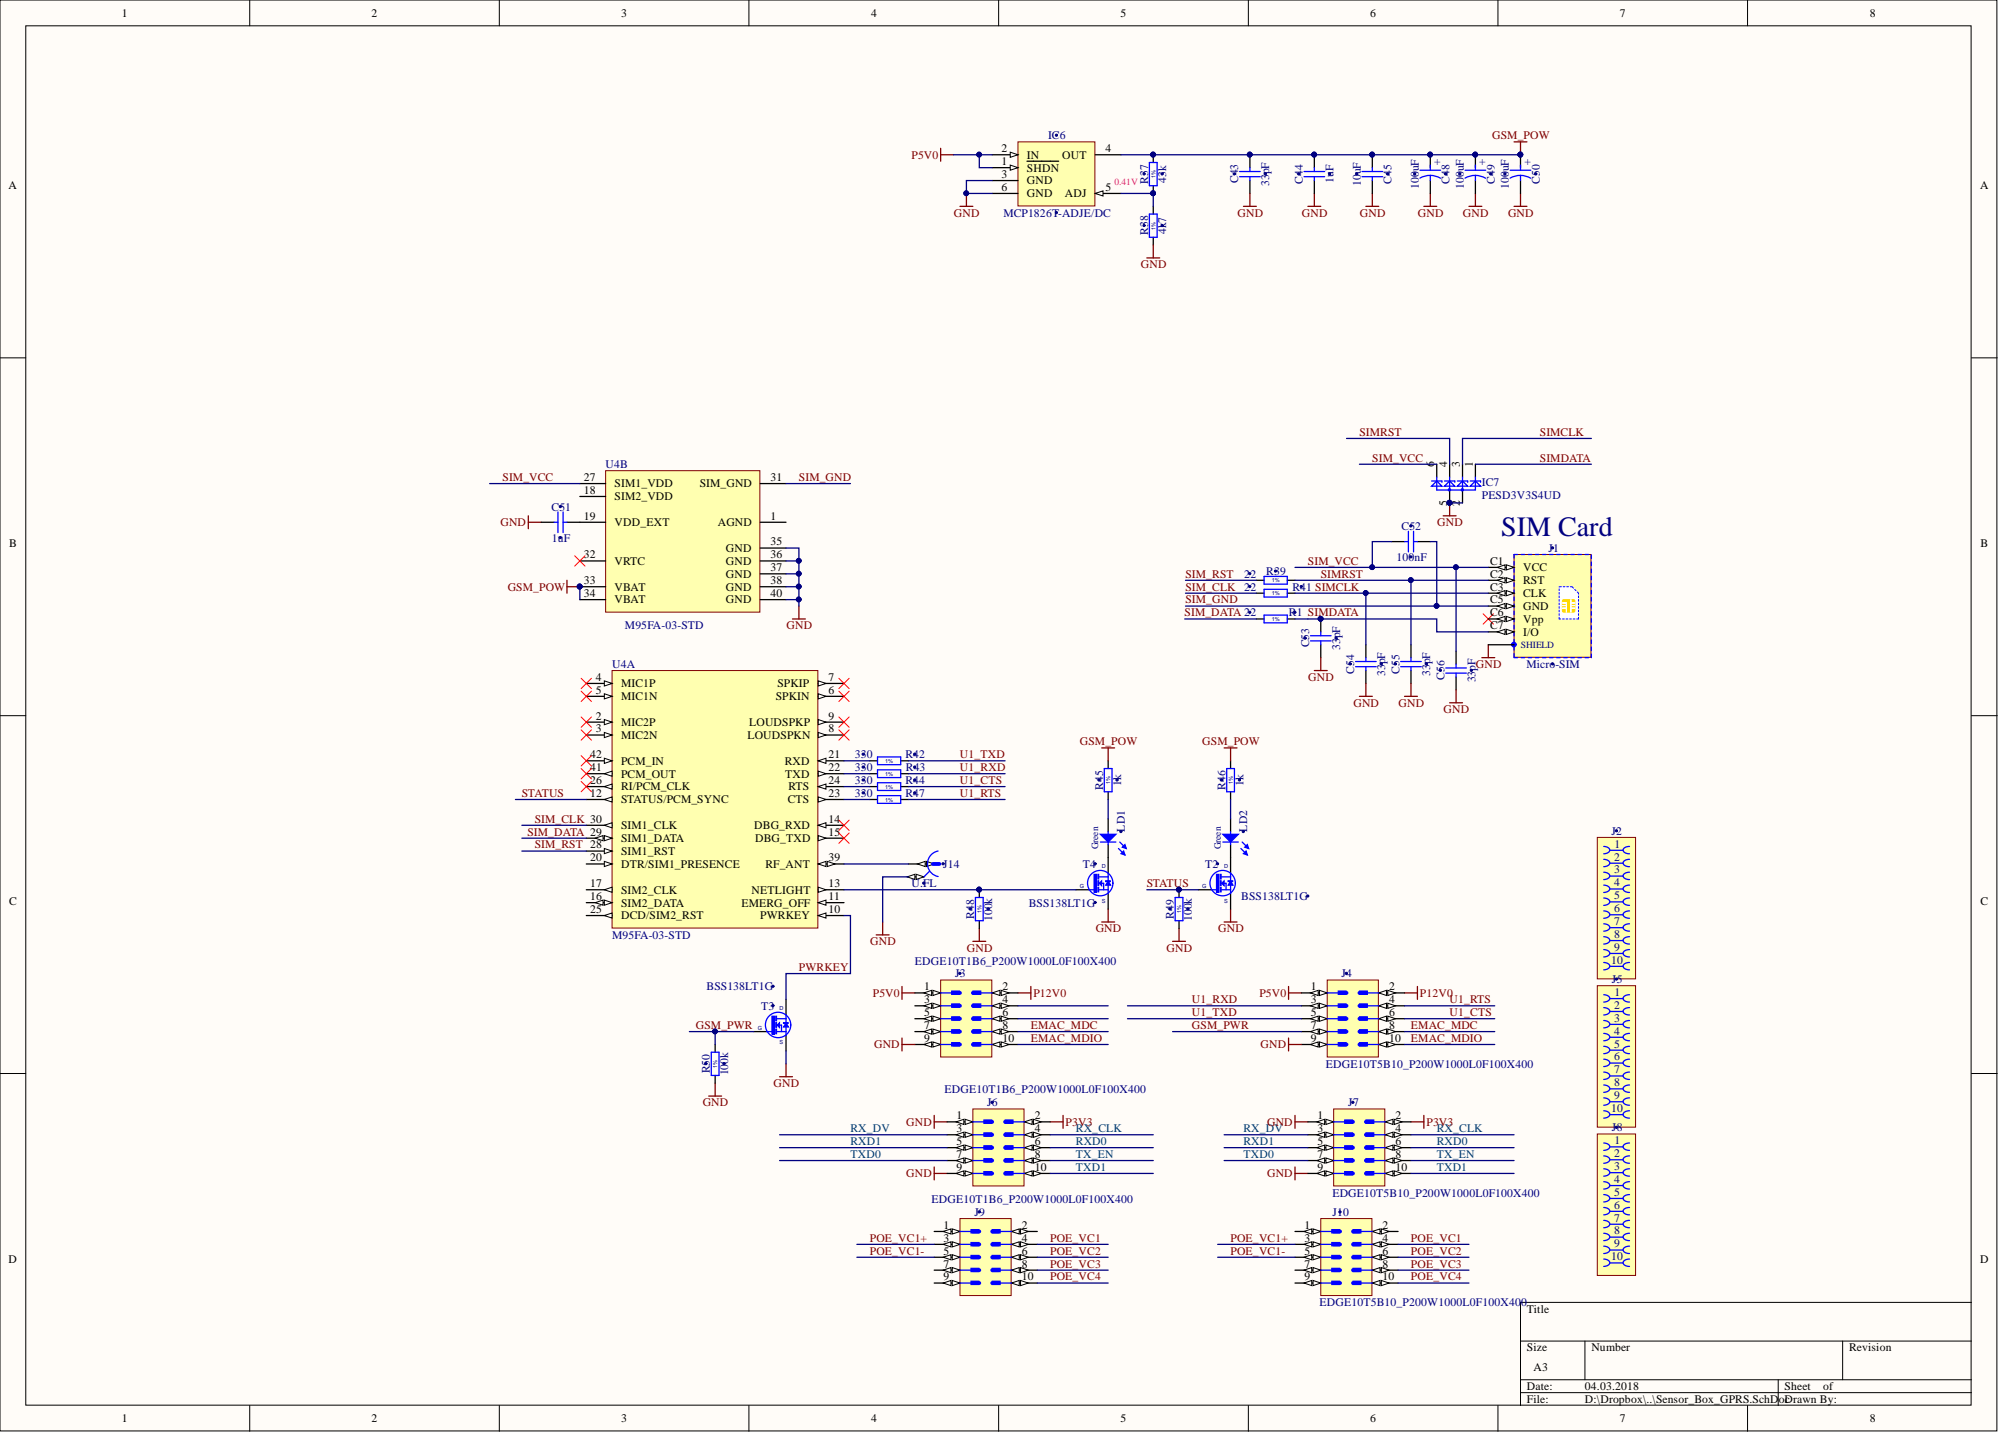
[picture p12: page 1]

RST C2
CLK C3
GND C5

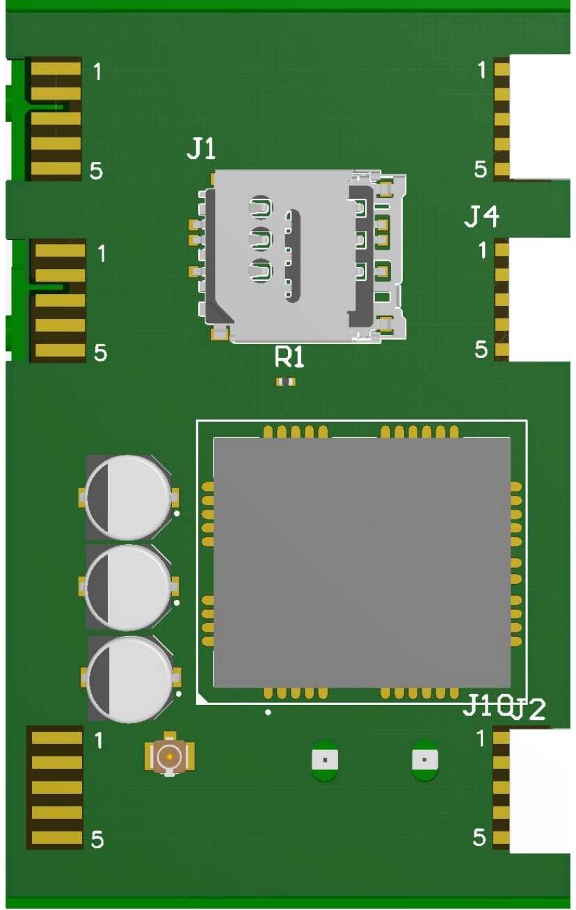
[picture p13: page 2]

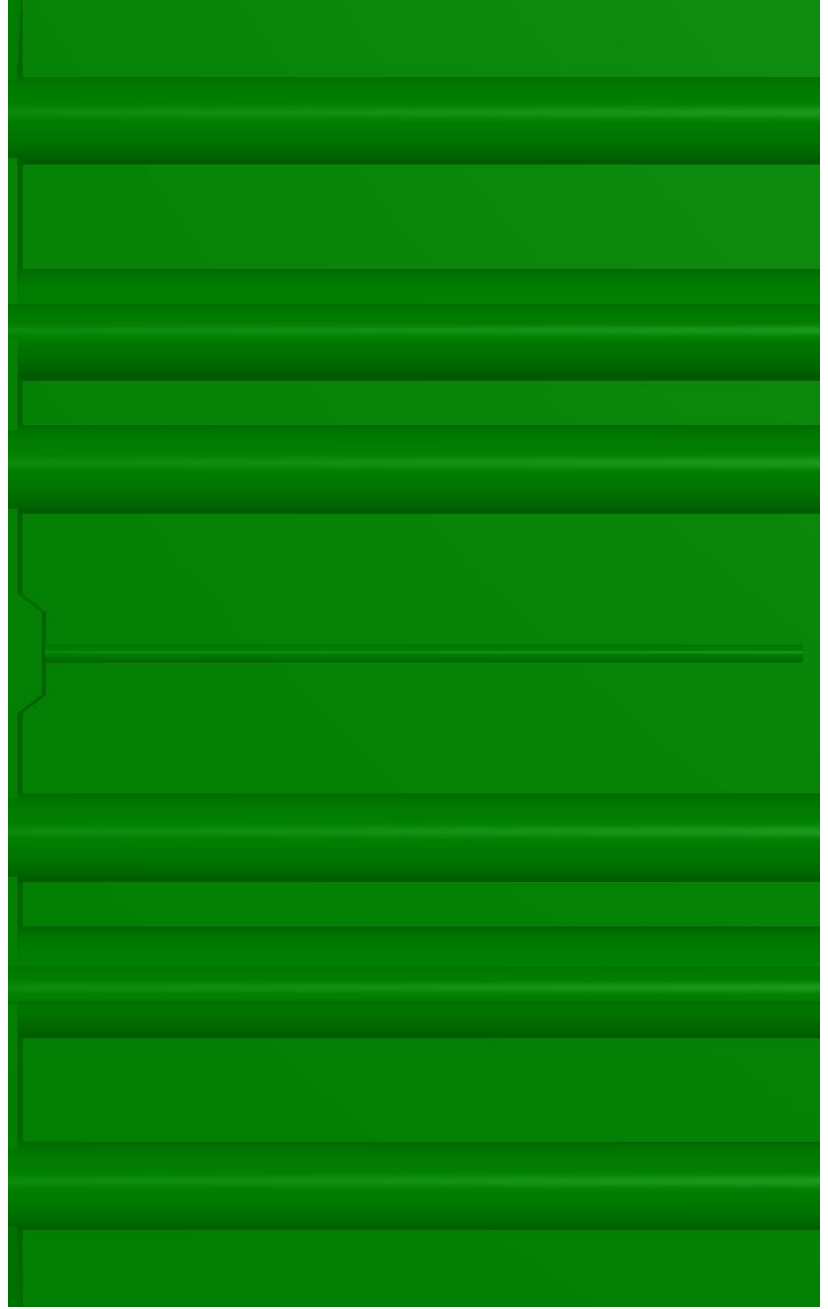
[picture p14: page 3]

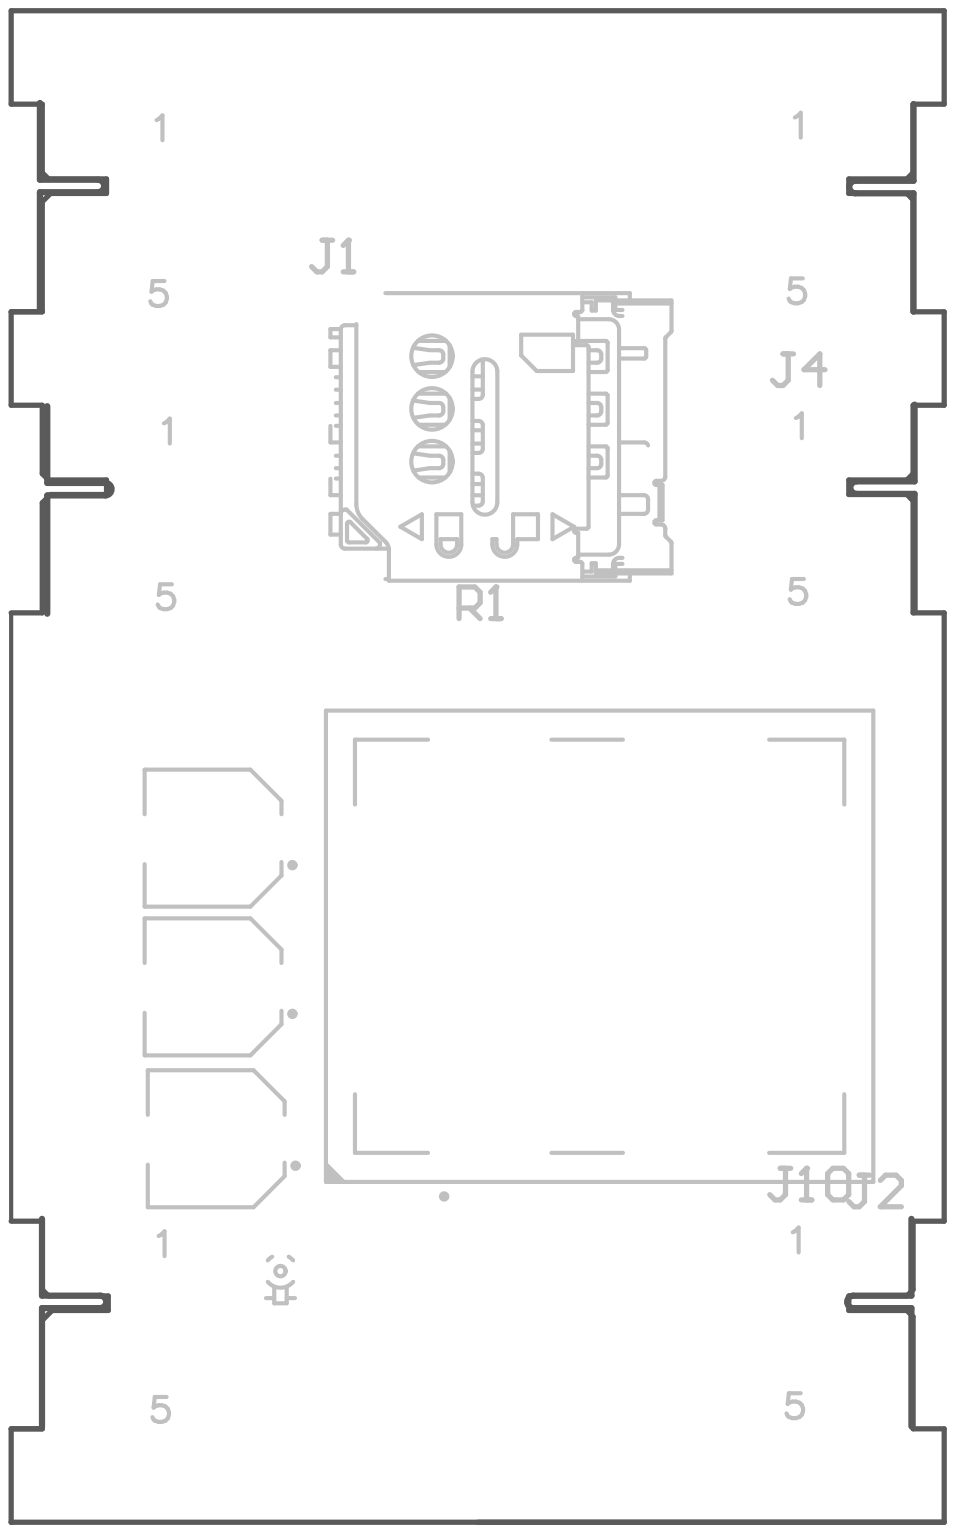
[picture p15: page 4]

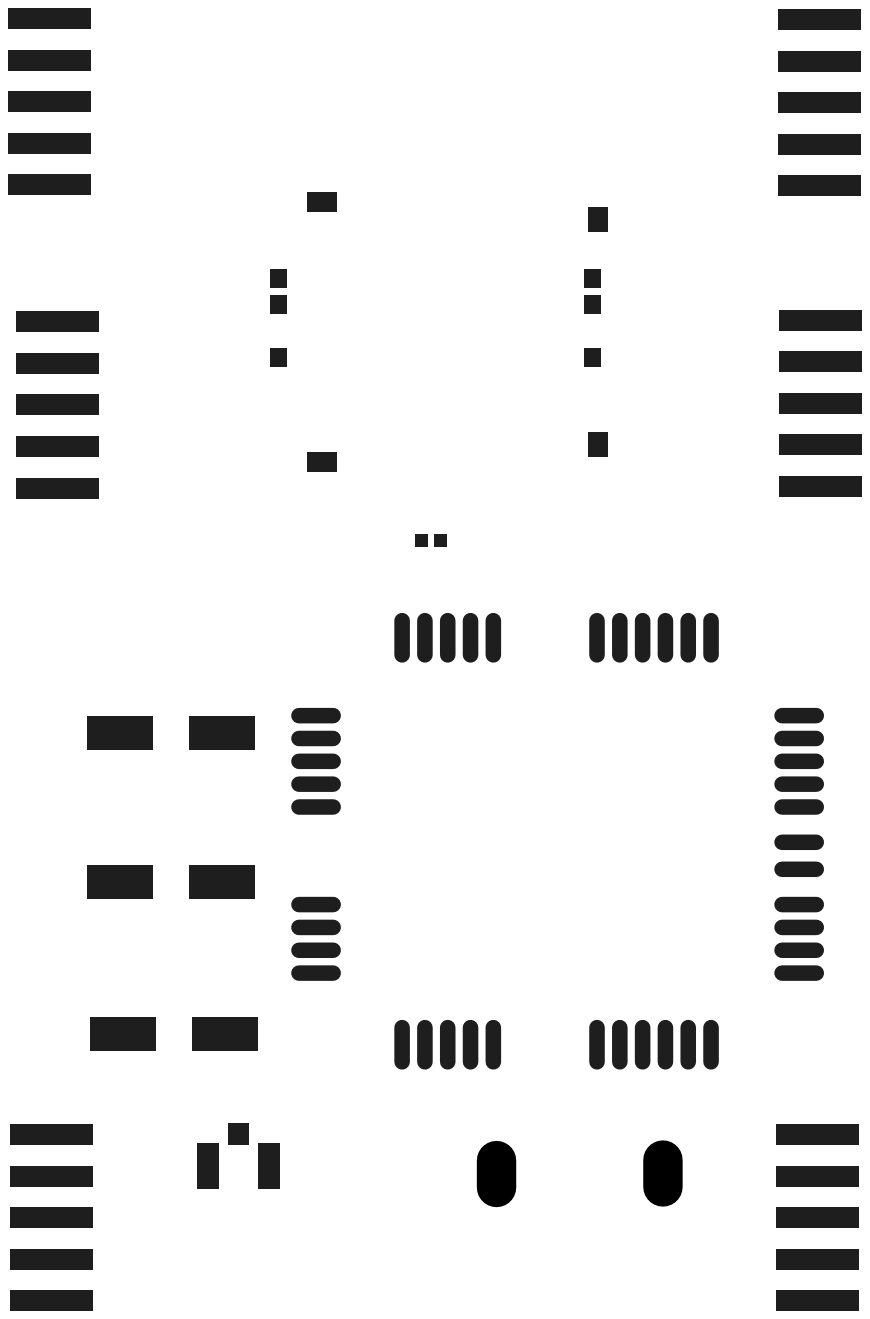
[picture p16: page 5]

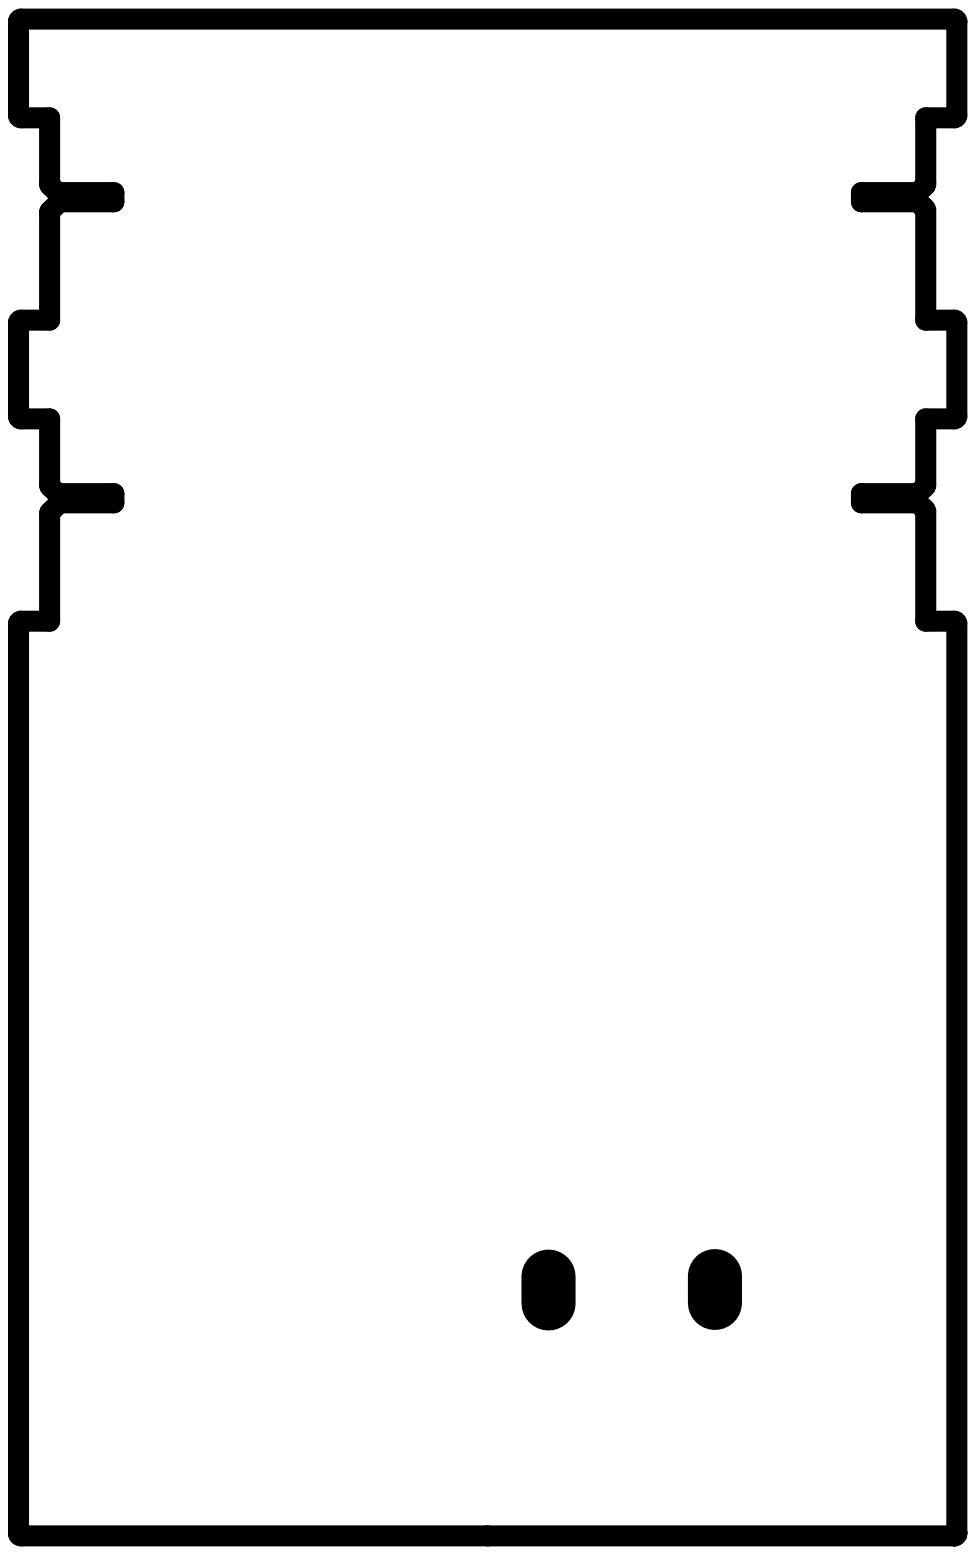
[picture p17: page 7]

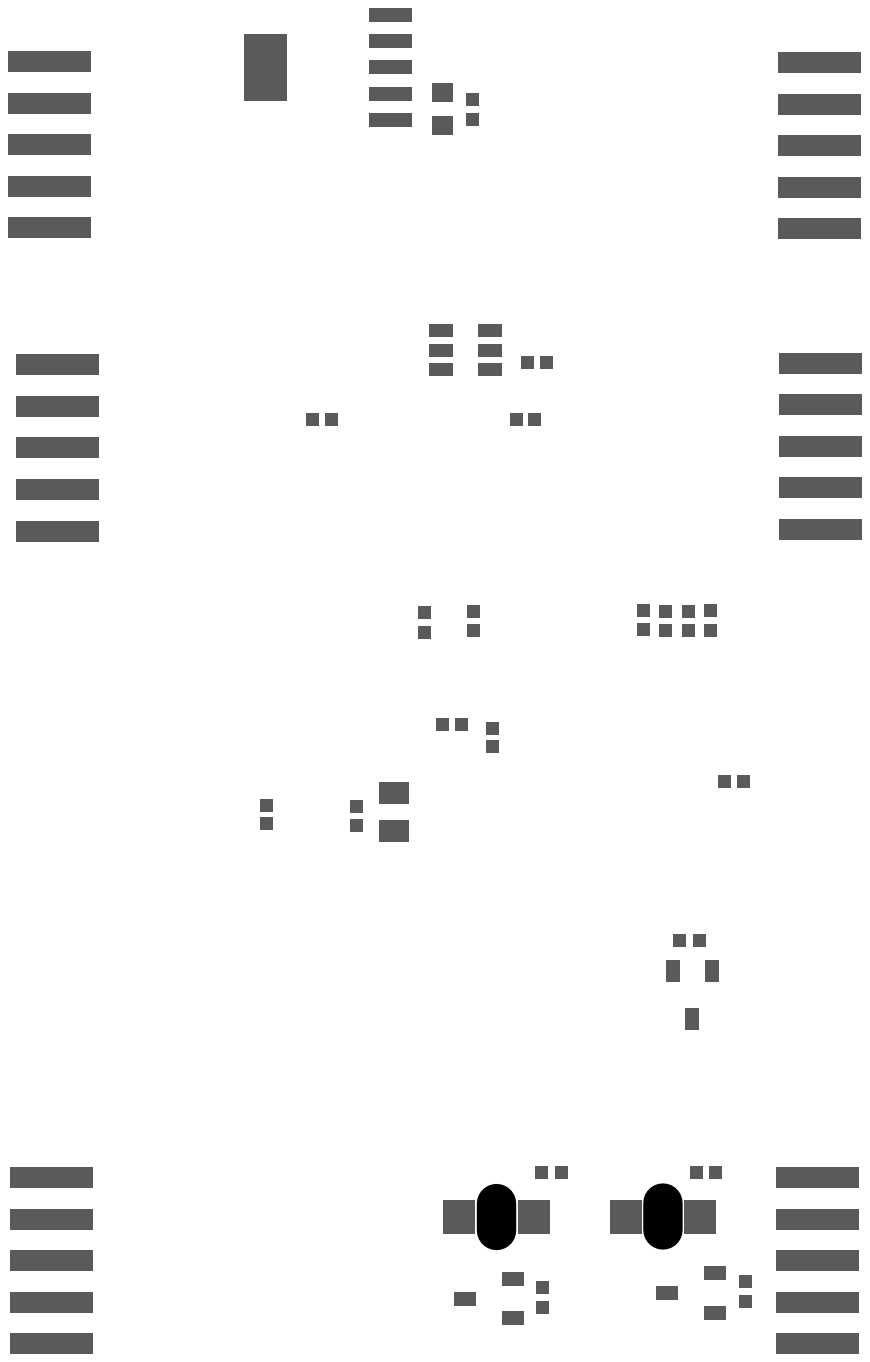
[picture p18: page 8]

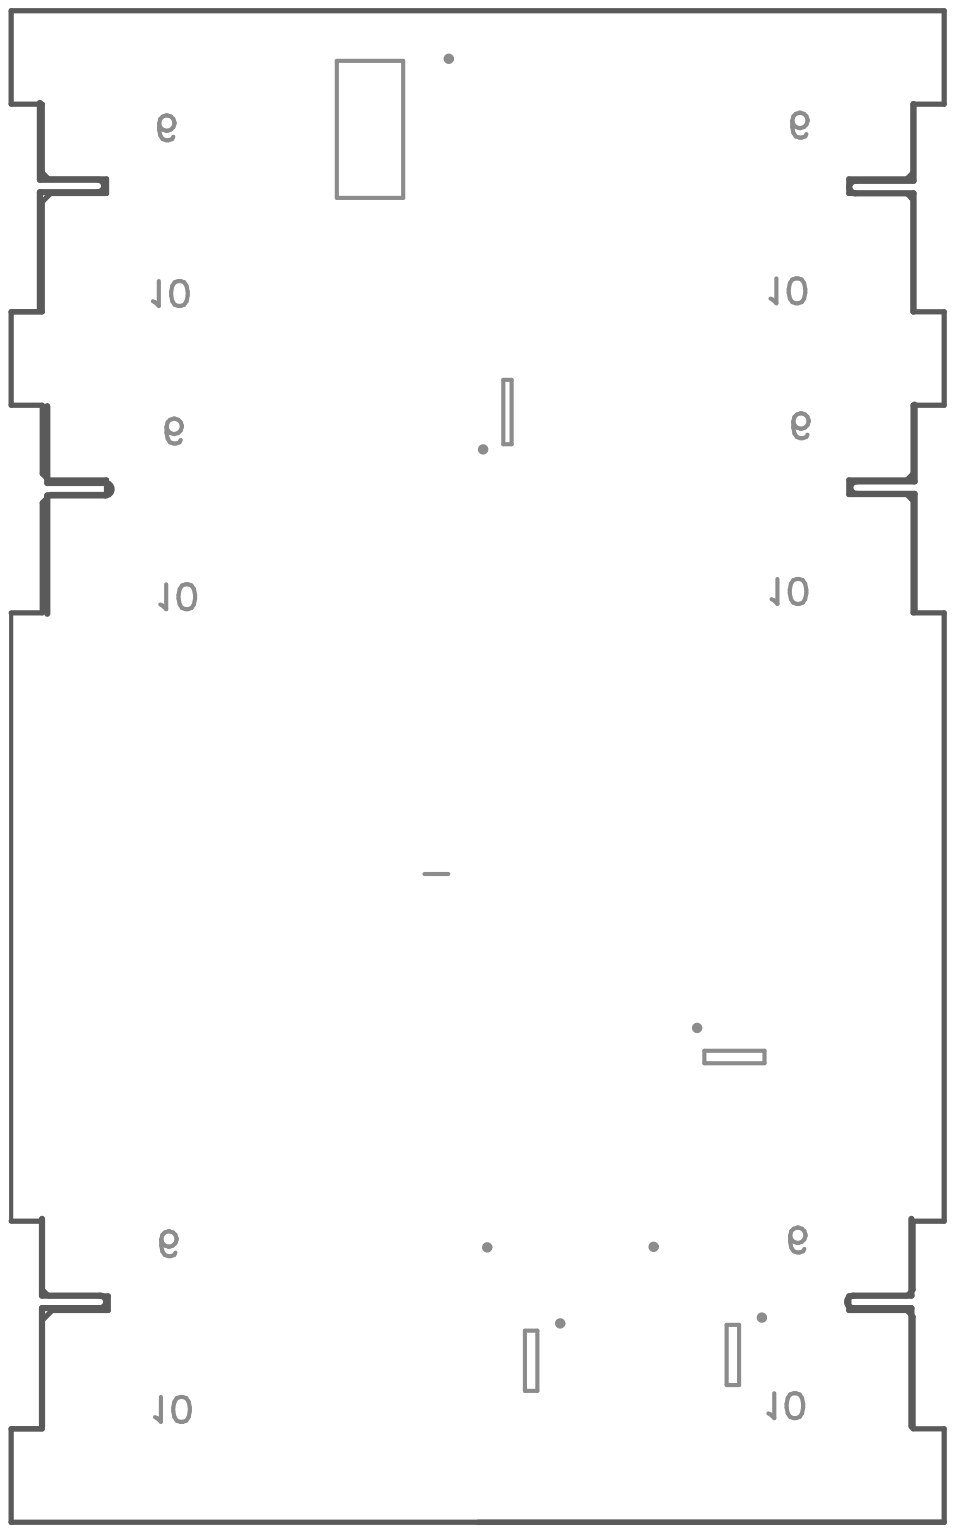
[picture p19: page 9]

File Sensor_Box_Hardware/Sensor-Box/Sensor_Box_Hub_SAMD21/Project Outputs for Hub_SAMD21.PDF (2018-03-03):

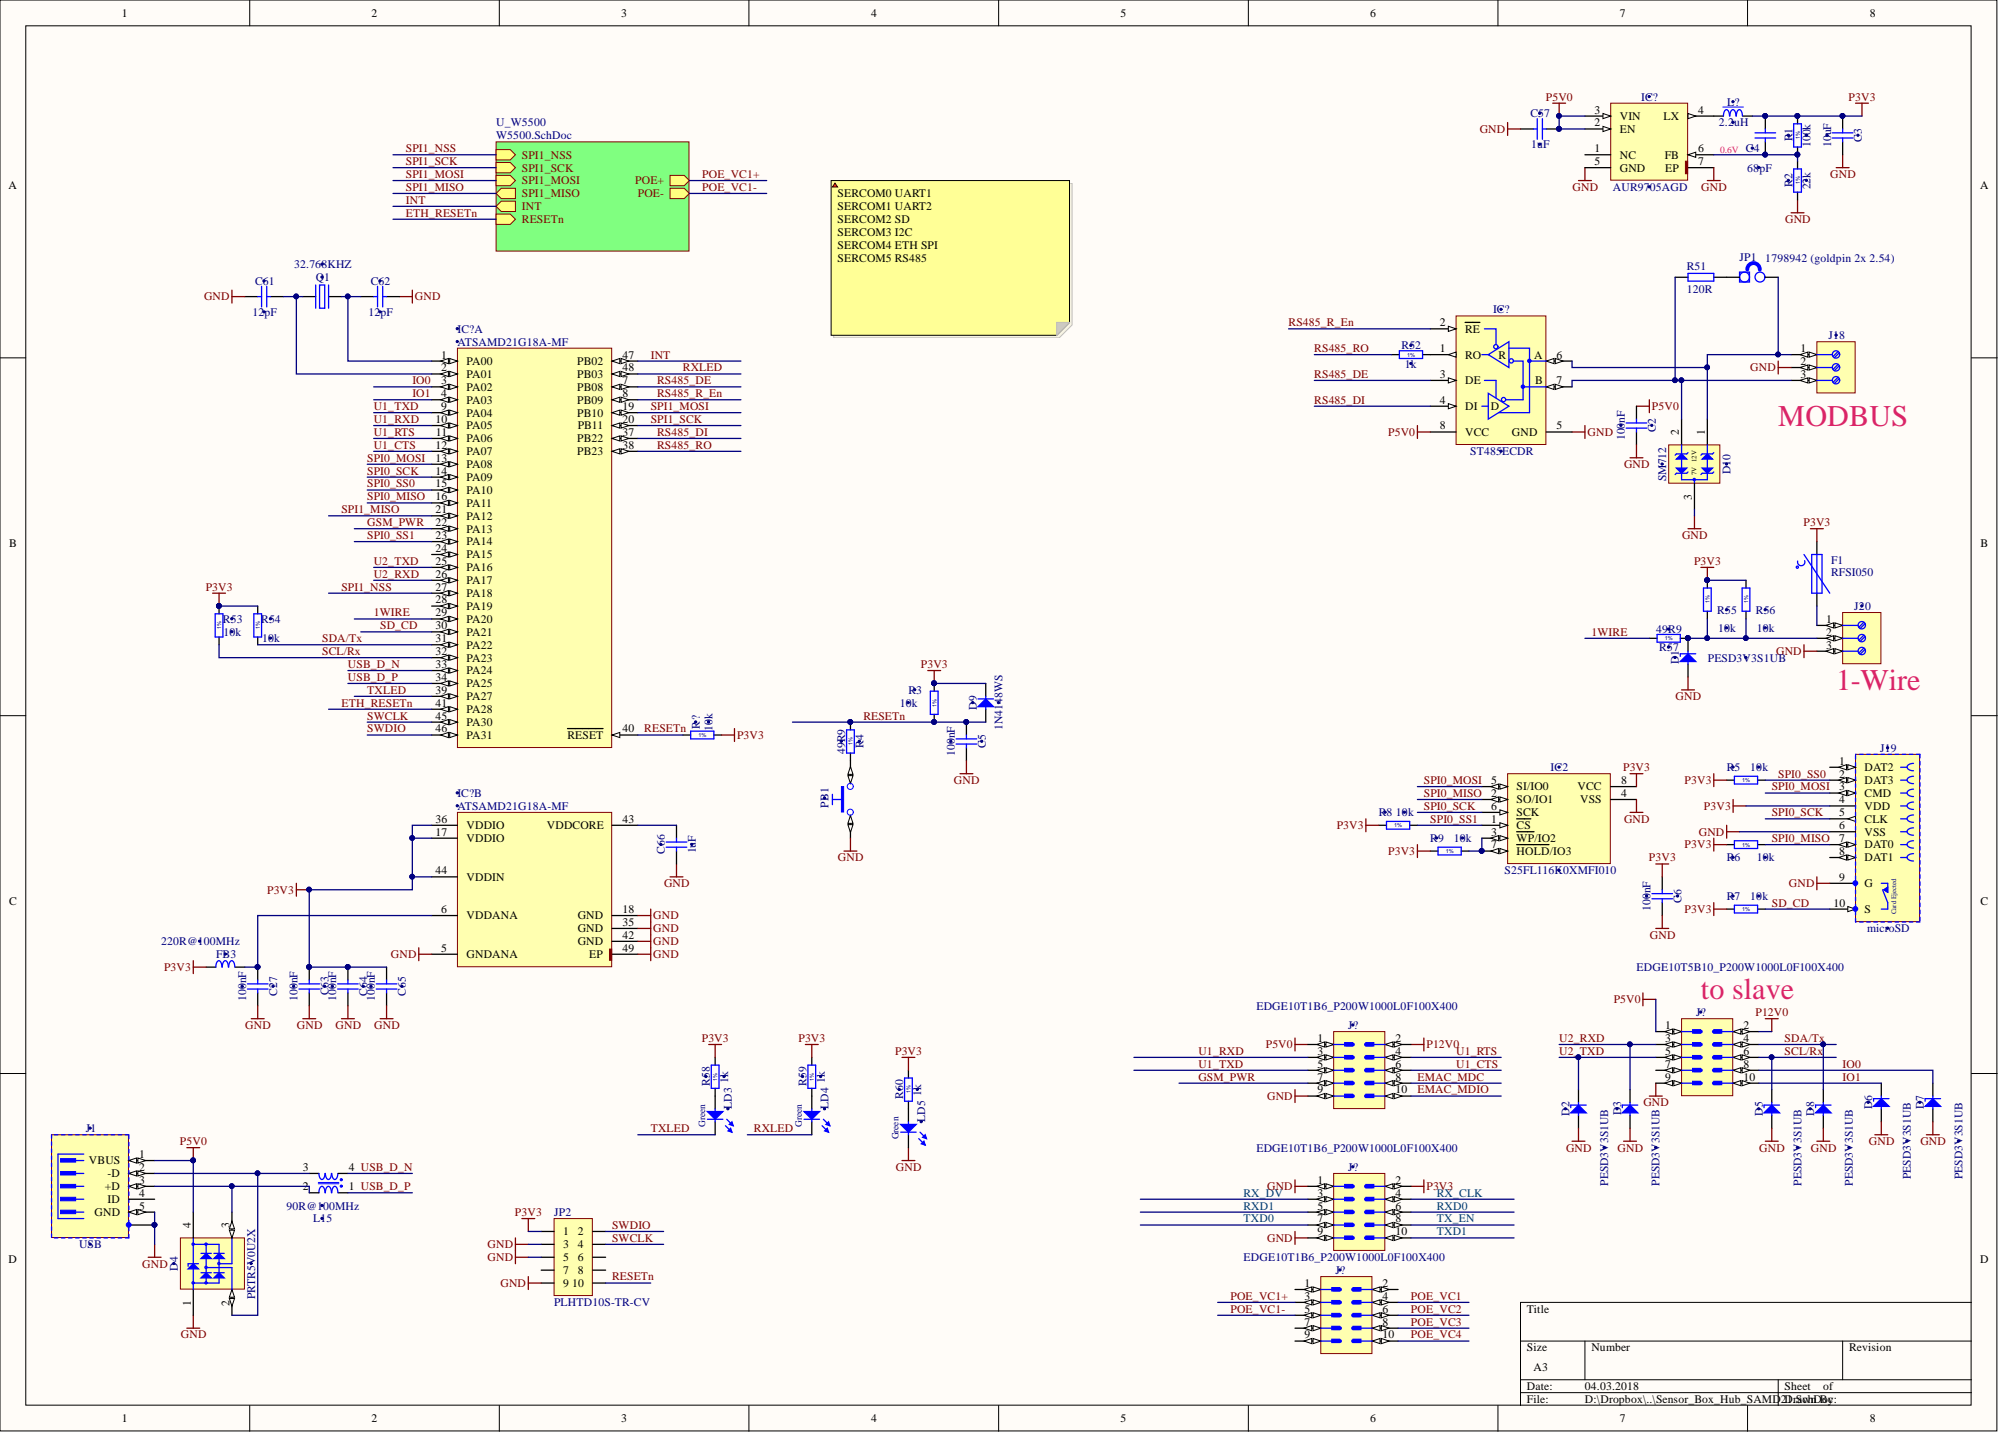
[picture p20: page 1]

6 U 1 _CT S | 7
8 EMAC_MD C | 9 | 1 0 | IO 1

5 ID 4

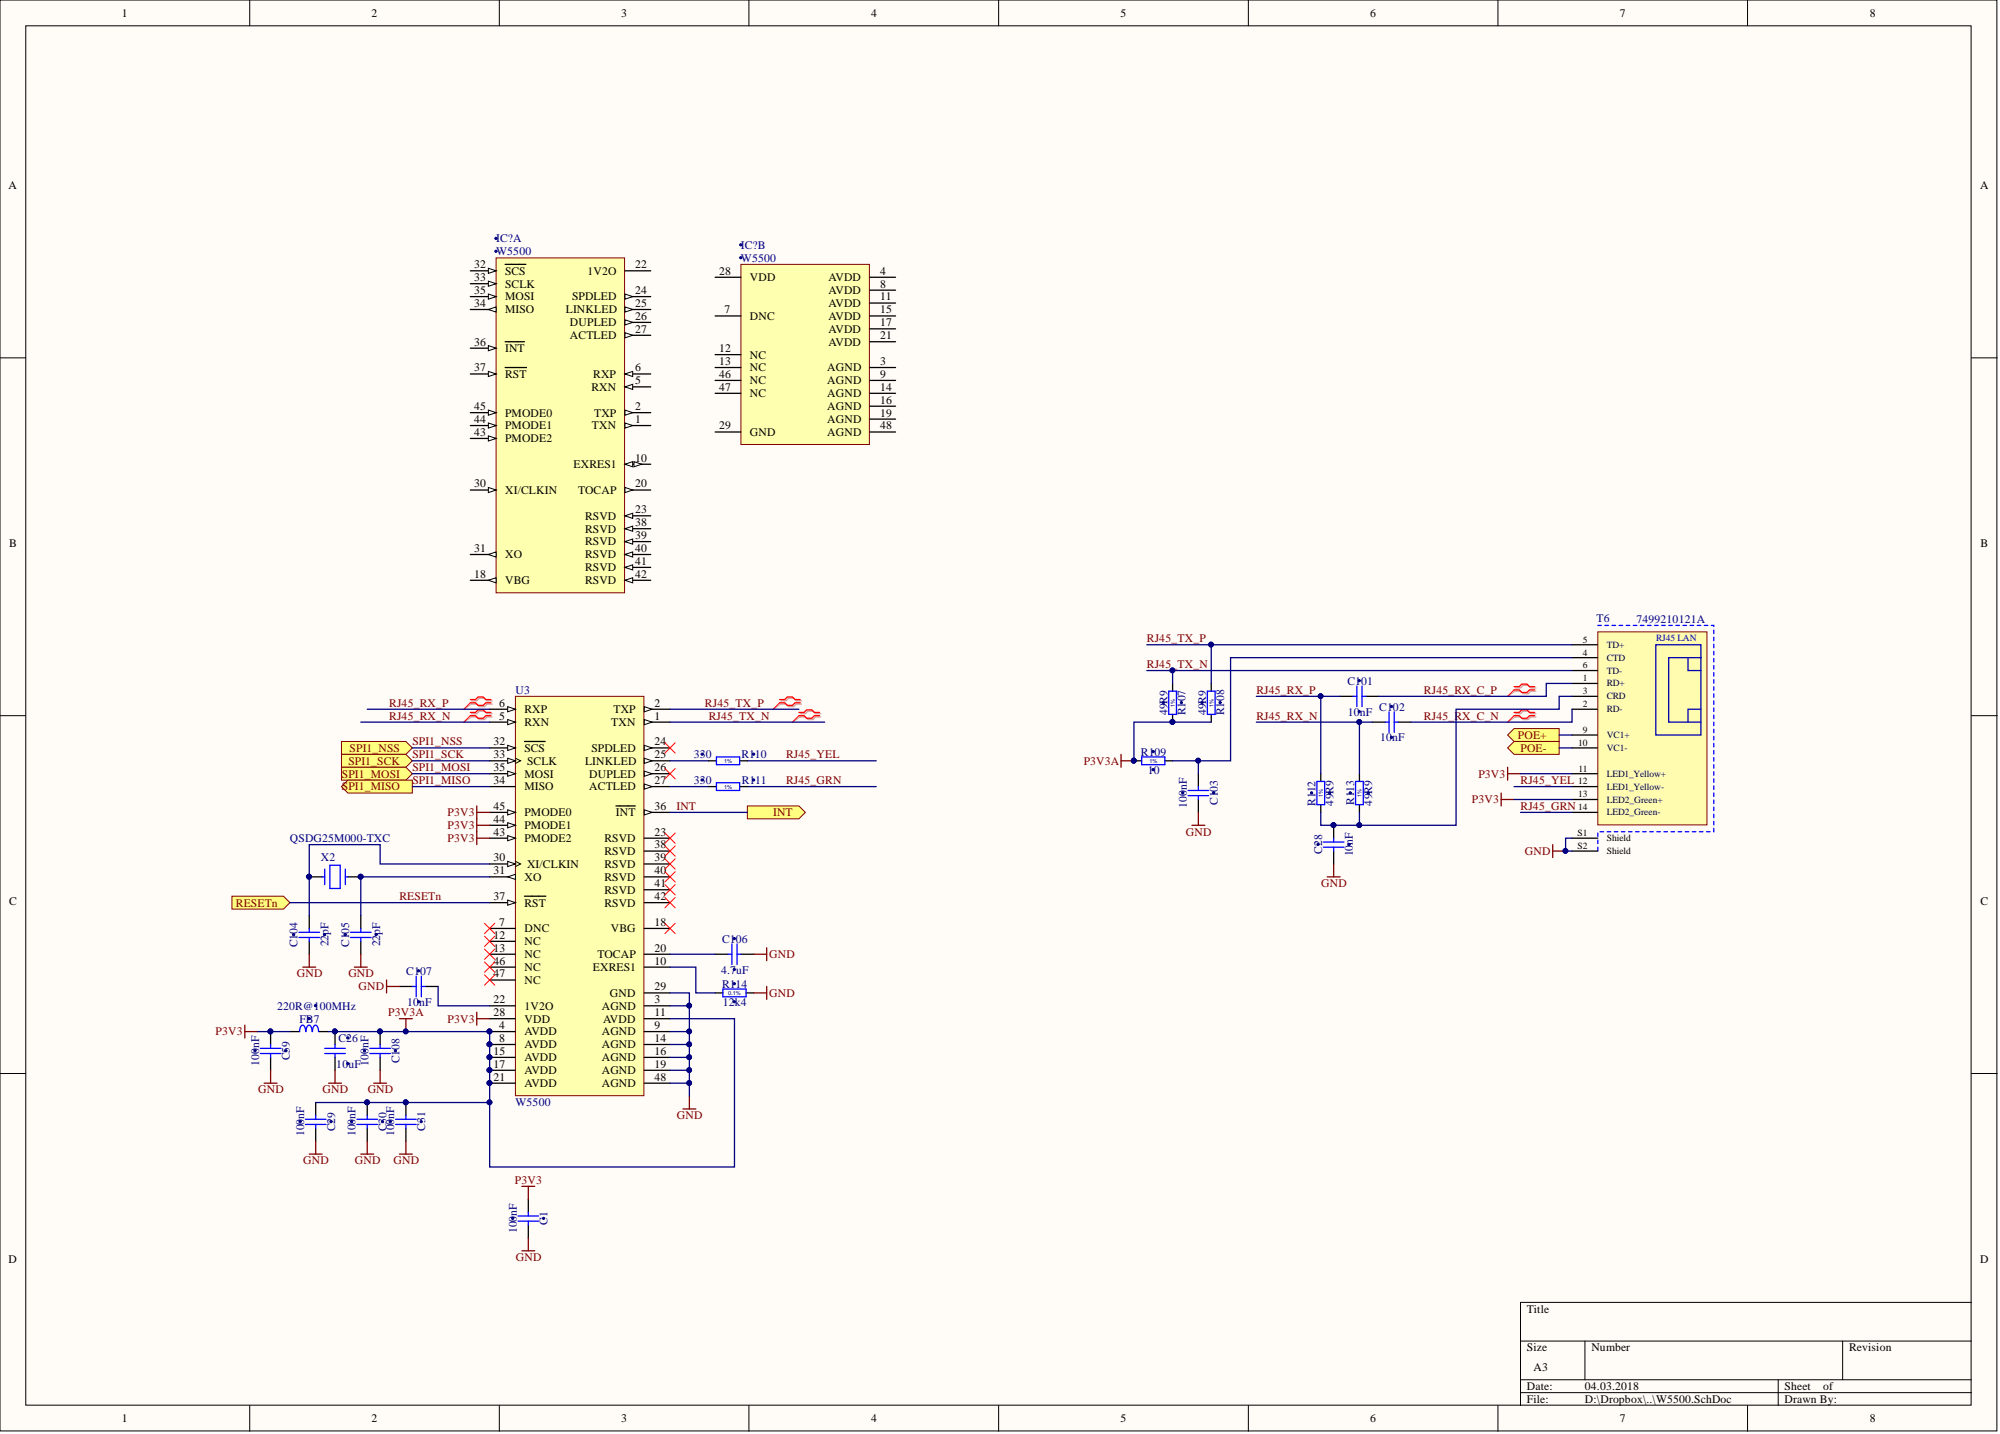
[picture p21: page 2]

2 9
3 | 0 . 1 %

4 | AV D D A G N D AV D D A G N D AV D D A G N D AV D D A G N D AV D D A G N D | 9 | D
8 | | 1 4
1 5 | | 1 6

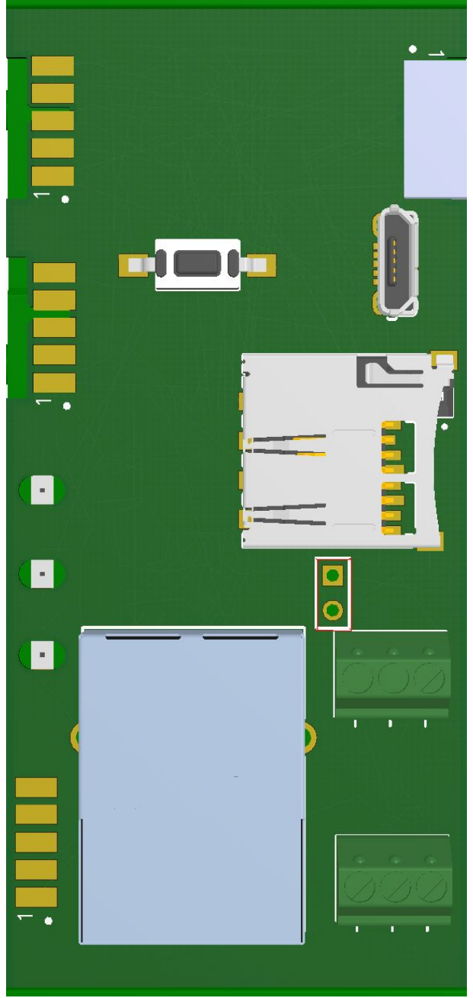
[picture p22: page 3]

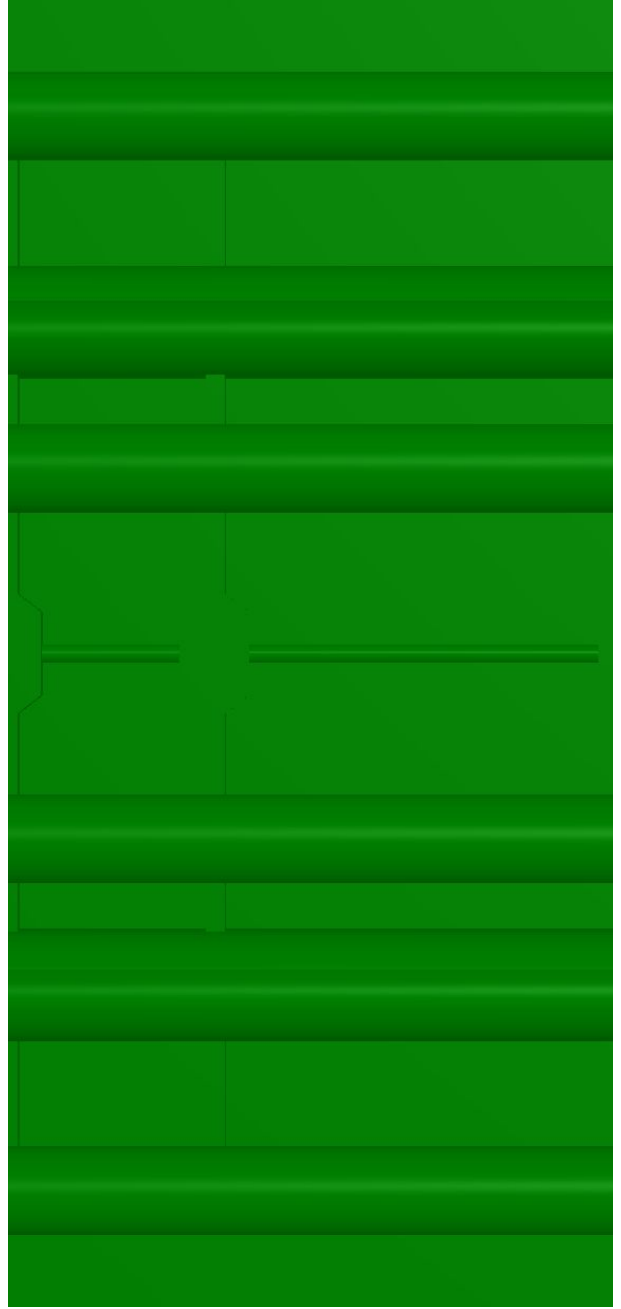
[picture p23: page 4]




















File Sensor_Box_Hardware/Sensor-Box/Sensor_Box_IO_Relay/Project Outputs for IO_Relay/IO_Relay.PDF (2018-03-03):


OUT_EN
1% | RxD















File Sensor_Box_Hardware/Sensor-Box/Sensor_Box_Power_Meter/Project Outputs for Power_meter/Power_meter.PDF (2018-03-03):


XOUT | PA09 8

CLK_8.192 RESETn SDA SCL | PA10 9 PA11 10 PA14 11 PA15 12 PA16 13

1% | E 13 | RxD

OUT_EN
1% | RxD


























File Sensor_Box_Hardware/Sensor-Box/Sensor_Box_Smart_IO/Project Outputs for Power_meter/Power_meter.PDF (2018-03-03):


XOUT | PA09/XOUT 8

SDA SCL | PA10/AIN[8] 9 PA11/AIN[9] 10 PA14/AIN[6] 11

1% | E 13 | RxD | 5 | 6 SCL/Rx







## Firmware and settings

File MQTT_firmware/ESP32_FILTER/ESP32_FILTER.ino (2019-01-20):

#include "credentials.h"
#include <Stepper.h>
#include <Wire.h>
#include "Arduino.h"
#include <Adafruit_SGP30.h>
#define SDA 13
#define SCL 15
#define EN_I2C1 26
#define EN_I2C2 27

#define CAYENNE_DEBUG

int current_pos = 0;
int desired_pos = 0;

//33    1   yellow    seq 3
//32    2   pink      seq 2
//vcc   3   red     
//35    4   orange    seq 4
//34    5   blue      seq 1
#define yellow 33
#define pink 32
#define orange 12
#define blue 14

#define CAYENNE_DEBUG
#define CAYENNE_PRINT Serial
#define CAYENNE_LOG Serial
#include <CayenneMQTTESP32.h>

Adafruit_SGP30 sgp;
const int stepsPerRevolution = 2048;  // change this to fit the number of steps per revolution
// initialize the stepper library on pins 2 through 5:
Stepper myStepper(stepsPerRevolution,  yellow, blue, pink,  orange);
//Stepper myStepper(stepsPerRevolution,  yellow, pink, blue,  orange);
//Stepper myStepper(stepsPerRevolution,    pink, yellow, orange, blue);
//Stepper myStepper(stepsPerRevolution,    pink, yellow, blue, orange);
//Stepper myStepper(stepsPerRevolution,    pink, blue, orange, yellow );
//Stepper myStepper(stepsPerRevolution,    pink, blue, yellow, orange);
//Stepper myStepper(stepsPerRevolution,    pink, orange, blue, yellow );
//Stepper myStepper(stepsPerRevolution,    pink, orange,yellow, blue );







unsigned long lastMillis = 0;




void setup()
{



 // set the speed at 60 rpm:
  myStepper.setSpeed(5);
  
  
  Serial.begin(115200);

  Serial.print("Connecting to ");
  Serial.println(ssid);

  // setup I2C switch
  pinMode (EN_I2C1, OUTPUT); 
  pinMode (EN_I2C2, OUTPUT); 
  digitalWrite(EN_I2C1, HIGH);
  digitalWrite(EN_I2C2, HIGH);
  Wire.begin( SDA,SCL, 1000000); 
  Wire.setClock(100000); // choose 100 kHz I2C rate

 Serial.println("SGP30 test");


  digitalWrite(EN_I2C1, HIGH);
  digitalWrite(EN_I2C2, HIGH);
while (! sgp.begin()){
    Serial.println("Sensor1 not found :(");
    delay(1000);
   // while (1);
  }
  Serial.print("Found SGP30_1 serial #");
  Serial.print(sgp.serialnumber[0], HEX);
  Serial.print(sgp.serialnumber[1], HEX);
  Serial.println(sgp.serialnumber[2], HEX);


//  digitalWrite(EN_I2C1, HIGH);
//  digitalWrite(EN_I2C2, HIGH);
//while (! sgp.begin()){
//    Serial.println("Sensor2 not found :(");
//    delay(1000);
//   // while (1);
//  }
//  Serial.print("Found SGP30_2 serial #");
//  Serial.print(sgp.serialnumber[0], HEX);
//  Serial.print(sgp.serialnumber[1], HEX);
//  Serial.println(sgp.serialnumber[2], HEX);
  

  // If you have a baseline measurement from before you can assign it to start, to 'self-calibrate'
  //sgp.setIAQBaseline(0x8E68, 0x8F41);  // Will vary for each sensor!



Cayenne.begin(username, password, clientID, ssid, wifiPassword);
Serial.print("Cayenne CFG done ");
myStepper.step(stepsPerRevolution);

}

int counter = 0;
int AV_CNT = 0;
int  TVOC1_AV =0;
int  eCO2_1_AV =0;
int RSSI_AV  = 0;

void loop()
{
    Cayenne.loop();
    
  if (current_pos != desired_pos) 
  {
  myStepper.step(current_pos - desired_pos);
  current_pos = desired_pos;
  }


  digitalWrite(EN_I2C1, HIGH);
  digitalWrite(EN_I2C2, HIGH);
  
  if (! sgp.IAQmeasure()) {
    Serial.println("Measurement1 failed");
    return;
  }
  Serial.print("TVOC_1 "); Serial.print(sgp.TVOC); Serial.print(" ppb\t");
  Serial.print("eCO2_1 "); Serial.print(sgp.eCO2); Serial.println(" ppm");

//  digitalWrite(EN_I2C1, HIGH);
//  digitalWrite(EN_I2C2, HIGH);
//
//  if (! sgp.IAQmeasure()) {
//    Serial.println("Measurement2 failed");
//    return;
//  }
//  Serial.print("TVOC_2 "); Serial.print(sgp.TVOC); Serial.print(" ppb\t");
//  Serial.print("eCO2_2 "); Serial.print(sgp.eCO2); Serial.println(" ppm");
  
delay(1000);
//   counter++;
//  if (counter == 30) {
//    counter = 0;
//
//    uint16_t TVOC_base, eCO2_base;
//    if (! sgp.getIAQBaseline(&eCO2_base, &TVOC_base)) {
//      Serial.println("Failed to get baseline readings");
//      return;
//    }
//    Serial.print("****Baseline values: eCO2: 0x"); Serial.print(eCO2_base, HEX);
//    Serial.print(" & TVOC: 0x"); Serial.println(TVOC_base, HEX);
//}



  

 if (AV_CNT++<10)
  {
  TVOC1_AV += sgp.TVOC;
  eCO2_1_AV += sgp.eCO2;
  RSSI_AV += WiFi.RSSI();
  }
else
  {
    AV_CNT=0;
      Serial.print("PTVOC: ");  
      Serial.print(TVOC1_AV);
      Serial.println("  ppb"); 
            
      Serial.print("eCO2: ");  
      Serial.print(eCO2_1_AV);
      Serial.println("  ppm");   
      Serial.println();
     // Cayenne.virtualWrite(0, lastMillis);
      Cayenne.virtualWrite(3,(float)(TVOC1_AV/10));
      Cayenne.virtualWrite(4,(float)(eCO2_1_AV/10),"co2","ppm");
      Cayenne.virtualWrite(2, (float)RSSI_AV/10, "snr", "db");
      TVOC1_AV = 0;
      eCO2_1_AV = 0;
      RSSI_AV = 0;
  }
  


    }

CAYENNE_IN(5)
{
  // get value sent from dashboard
 desired_pos = getValue.asInt() * 50;
}

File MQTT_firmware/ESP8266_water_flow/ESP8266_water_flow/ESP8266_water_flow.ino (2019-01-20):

#include "credentials.h"



#define CAYENNE_PRINT Serial
#include <OneWire.h>
#include <DallasTemperature.h>
#include <CayenneMQTTESP8266.h>
#include <Ticker.h>
#define TEMP_PIN V2
const int tmpPin = 12;
#define LED D0
#define timer_per 500000  //50 ms   0.2us/tick
OneWire oneWire(tmpPin);
DallasTemperature sensors(&oneWire);




unsigned long lastMillis = 0;
// Virtual Pin of the DS18B20 widget.
#define TEMP_PIN V2
#define VIRTUAL_PIN V1
int volume;
int flow;
int valve_desired_pos;
int valve_current_pos;


bool tickOccured;
bool dmpulse;
int cnt_60s = 0;
int cnt_1s = 0;
int volume_old;

// interrupt routines

//=======================================================================

// ISR every 50ms
void ICACHE_RAM_ATTR onTimerISR(){
    //digitalWrite(LED,!(digitalRead(LED)));  //Toggle LED Pin
    tickOccured = true;
    timer1_write(timer_per);

    if (dmpulse == true) {
      dmpulse = false;
      volume ++;
    }
    
    if (cnt_60s == 600) {
      //digitalWrite(LED,!(digitalRead(LED)));  //Toggle LED Pin
      cnt_60s = 0;
      flow = volume - volume_old;
      volume_old = volume;
    }
    cnt_60s++;

   // if (cnt_1s == 10) {
   //   digitalWrite(LED,!(digitalRead(LED)));  //Toggle LED Pin
    //  cnt_1s = 0;

     if (valve_current_pos != valve_desired_pos) 
    {
    if (valve_current_pos >= valve_desired_pos){
      digitalWrite(15, HIGH);
      digitalWrite(13, LOW);
      valve_current_pos--;
    }
       if (valve_current_pos < valve_desired_pos){
      digitalWrite(15, LOW);
      digitalWrite(13, HIGH);
      valve_current_pos++;
    }
    }
    else {
      digitalWrite(15, LOW);
      digitalWrite(13, LOW);
    }


    //}
   // cnt_1s++;




    
    
}


void dm_isr() {
  dmpulse = true;

}

void right() {
  digitalWrite(15, HIGH);   // turn the LED on (HIGH is the voltage level)
  digitalWrite(13, LOW);   // turn the LED on (HIGH is the voltage level)
}



void setup() {
  // initialize digital pin 13 as an output.
  pinMode(13, OUTPUT);
  pinMode(15, OUTPUT);
  pinMode(0, OUTPUT);
  digitalWrite(0, LOW); // GND for flow meter contact to mitigate startup pullup requirement for 0 and 2
  pinMode(2, INPUT);
  pinMode(LED,OUTPUT);
  Serial.begin(9600);   // GPIO1, GPIO3 (TX/RX pin on ESP-12E Development Board)
  Serial.println("started");
  attachInterrupt(2, dm_isr, FALLING);
  //attachInterrupt(0, right, FALLING);
  Cayenne.begin(username, password, clientID, ssid, wifiPassword);
  //toggle();
  tickOccured = false;
  volume_old=0;
  volume = 0;
  
    timer1_attachInterrupt(onTimerISR);
    timer1_enable(TIM_DIV16, TIM_EDGE, TIM_SINGLE);
    timer1_write(timer_per); 

    valve_desired_pos=0;
    valve_current_pos=200; // force closing at startup

}

// the loop function runs over and over again forever
void loop() {
  Cayenne.loop();
//  digitalWrite(13, HIGH);   // turn the LED on (HIGH is the voltage level)
//  digitalWrite(15, LOW);   // turn the LED on (HIGH is the voltage level)
//  delay(1000);              // wait for a second
//  digitalWrite(13, LOW);    // turn the LED off by making the voltage LOW
//  digitalWrite(15, HIGH);   // turn the LED on (HIGH is the voltage level)
//  delay(1000);              // wait for a second

  //if (digitalRead(0) == LOW)  {Serial.println("pin0");}
  //if (digitalRea

    //Publish data every 10 seconds (10000 milliseconds). Change this value to publish at a different interval.
  if (millis() - lastMillis > 10000) {
          lastMillis = millis();
          sensors.requestTemperatures();
          Serial.println("tmp1");
          Serial.println( sensors.getTempCByIndex(0));
          Serial.println("tmp2");
          Serial.println( sensors.getTempCByIndex(1));
          Cayenne.celsiusWrite(1, sensors.getTempCByIndex(0));
          Cayenne.celsiusWrite(2, sensors.getTempCByIndex(1));
          Cayenne.virtualWrite(3, valve_current_pos);
          Cayenne.virtualWrite(4, WiFi.RSSI(), "snr", "db");
          Cayenne.virtualWrite(7, volume, "Liter", "l");
          Cayenne.virtualWrite(8, flow, "Liter", "l");

          }

 if (tickOccured == true)
 {

    Serial.println("volume");
    Serial.println(volume);
    Serial.println("flow");
    Serial.println(flow);
    tickOccured = false;
    Serial.println("pos");
    Serial.println(valve_current_pos);

 }


  

}


CAYENNE_IN(5)
{
  // get value sent from dashboard
    
    Serial.println("in5");
Serial.println( getValue.asInt());
 valve_desired_pos = getValue.asInt() ;
 if (valve_desired_pos >100){
  valve_desired_pos = 100;
 }
 
}


CAYENNE_IN(6)
{
  // get value sent from dashboard
  int currentValue = getValue.asInt(); // 0 to 1
  if (currentValue == 1) {
    valve_desired_pos=0;
    valve_current_pos=200; // force closing at startup
  }
}

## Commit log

2017-12-03 repo init, added old designs of similar hardware
    [ACC_charger.SchDoc, AC_SUPPLY.SchDoc, ADCs.SchDoc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]
2018-01-22 added schematics for modules: Ethernet PHY, PoE, power meter, GPRS, DC input, AC supply, SAMD21 controller, ESP32 controller, relay IO, simple IO
    [CPU.SchDoc, Common_Sensor_Box.PCBDOC, Common_Sensor_Box.PrjPCB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]
2018-01-22 added pdf docs
    [Common_Sensor_Box.PCBDOC, ETH_Wifi.SCHDOC, Weather_Station_ETH.PRJPCB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]
2018-03-03 added CAN switch, schematic update for all boards
    [Common_Sensor_Box.PCBDOC, Power_meter.PCBDOC, Power_meter.SchDoc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]
2018-06-03 finished routing of all 18 modules
    [Common_Sensor_Box.PCBDOC, Common_Sensor_Box.PrjPCB, Common_Sensor_Box.SchDoc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]
2018-06-30 added support for Onion Omega 2 and STM32-based CAN controller
    [Sensor_Box_Ethernet.SchDoc, Sensor_Box_Hub_OrangePi.SchDoc, Sensor_Box_Hub_SAMD21.PCBDOC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]
2018-07-01 BOM optimisation
    [Common_Sensor_Box.PCBDOC, Common_Sensor_Box.PrjPCB, Common_Sensor_Box.SchDoc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]
2018-07-08 added firmware update memory, added alternative STM32 CAN controller
    [Common_Sensor_Box.PCBDOC, Common_Sensor_Box.PrjPCB, Common_Sensor_Box.SchDoc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]
2019-01-20 fimware update
    [Arduino_box.stl, Bottom.stl, Bottom.stp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]
2019-02-25 added RTD module, schematic and PCB cleanup
    [Common_Sensor_Box.PCBDOC, Common_Sensor_Box.PrjPCB, Common_Sensor_Box.SchDoc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]
2022-01-12 CPU replaced with Cortex M0 RAK module
    [Sensor_LoRa_Flower_Watchdog.PCBDOC, Sensor_LoRa_Flower_Watchdog.SchDoc, Sensor_LoRa_Moist.PCBDOC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]
